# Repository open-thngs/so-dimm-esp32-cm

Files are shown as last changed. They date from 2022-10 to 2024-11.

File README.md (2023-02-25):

# SO-DIMM-ESP32-S2-CM

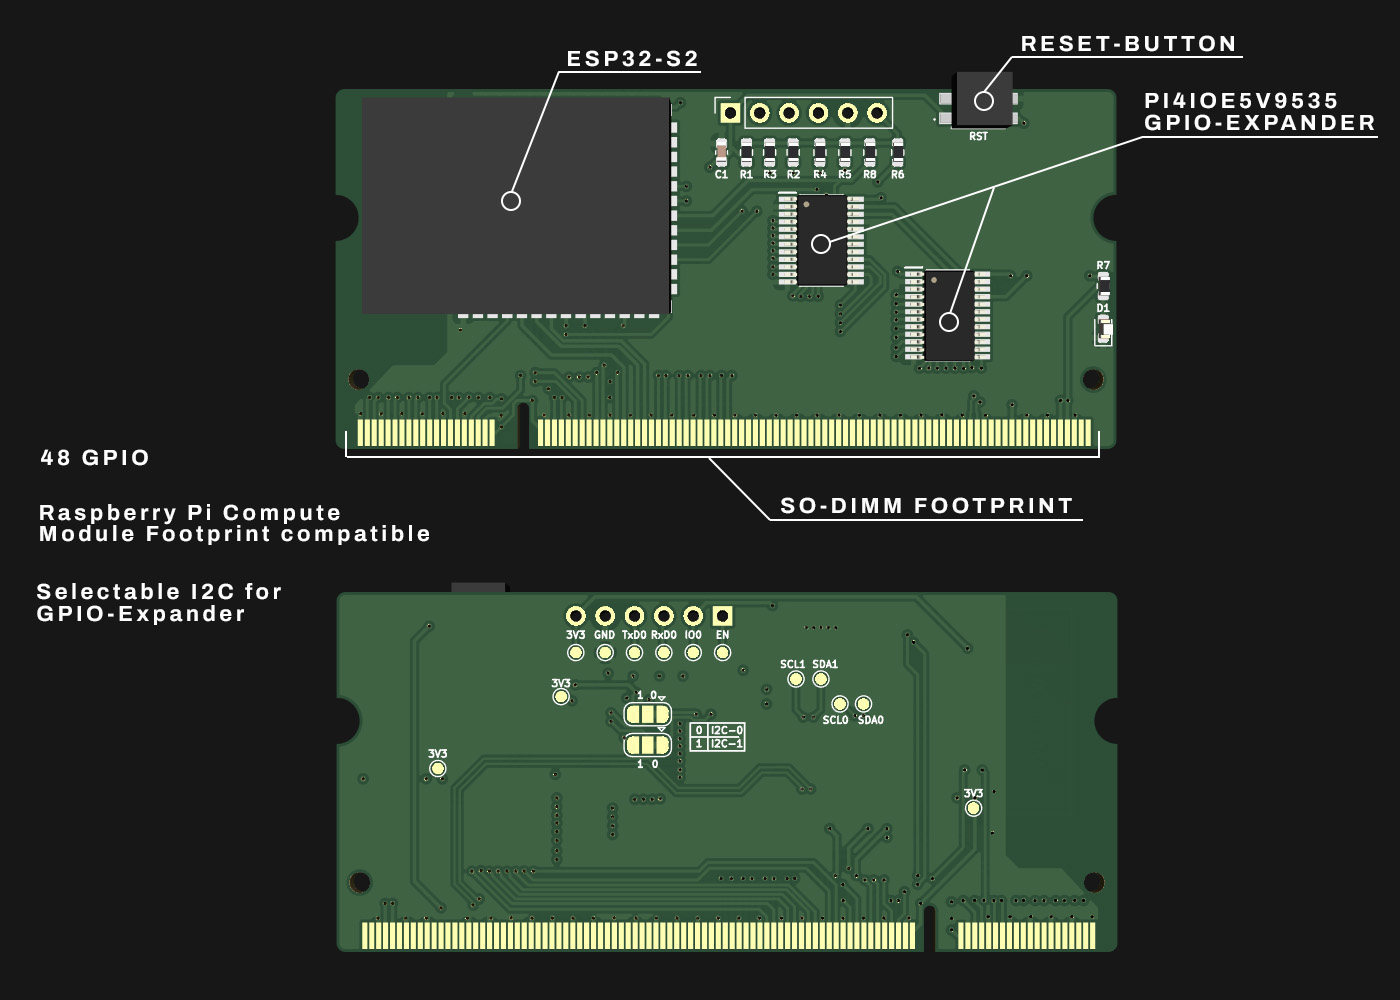
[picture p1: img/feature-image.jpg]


This is a ESP32-S2 based Compute Module to replace the Raspberry Pi's Compute Modules CM2 and CM3. This module is footprint compatible to the Raspberry Pi CM (SO-DIMM-DDR2). The ESP32-S2 brings USB, I2C and SPI.

Because the ESP32 is not running a Linux OS this module can not replace any CM in any project due to its limitations but it might helps others to reduce cost and resources needed to run the project. The ESP32-S2 consumes only 1/3 of the power the CM does. The ESP can also bring WiFi to your project if needed.

The Module also contains 2x GPIO-Expander which are used to be compatible with any GPIO of the Raspberry Pi Compute Module which gives you 48 GPIOs to be used in total.

Features:
- 2x I2C
- 2x SPI
- 1x UART
- USB

## OSHW Certified

[OSHW] DE000133 | Certified open source hardware | oshwa.org/cert

[https://certification.oshwa.org/de000133.html](https://certification.oshwa.org/de000133.html)

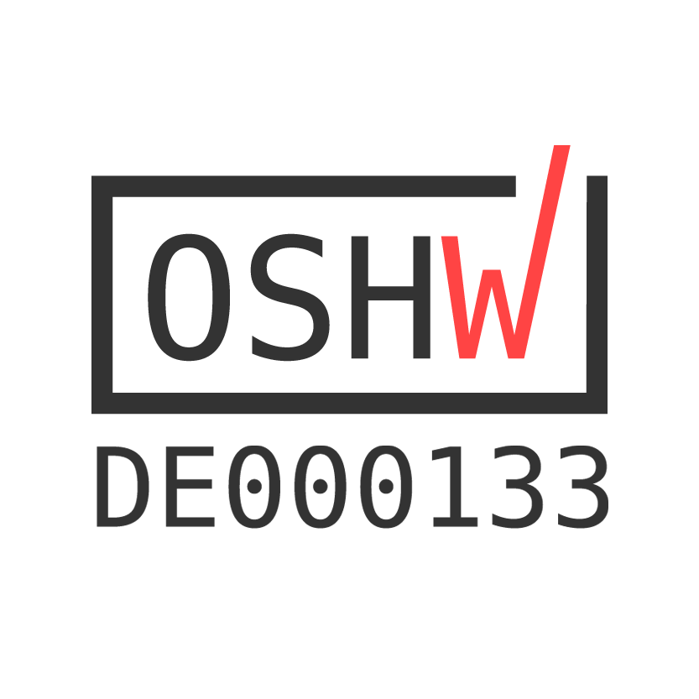
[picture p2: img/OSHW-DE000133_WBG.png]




## GPIO Reference

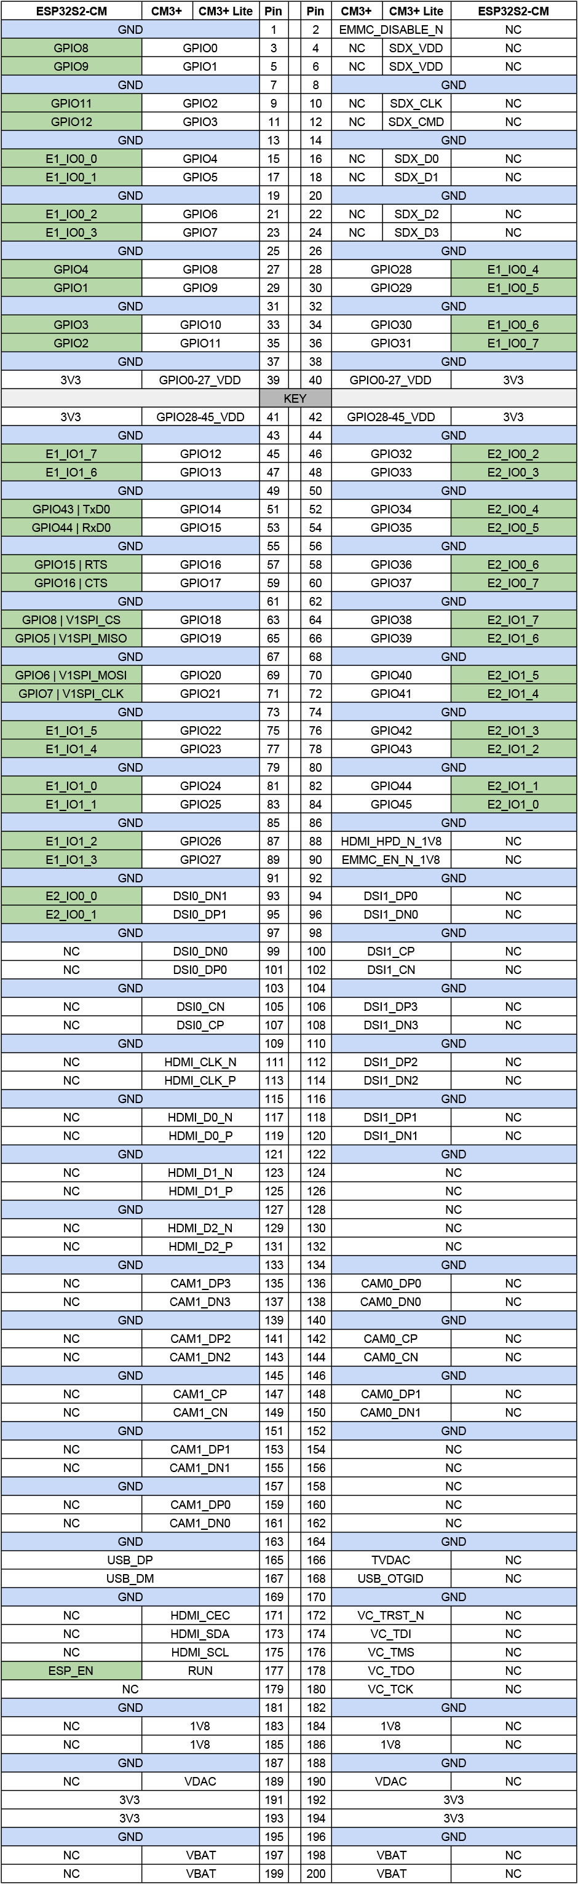
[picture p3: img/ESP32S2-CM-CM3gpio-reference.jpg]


GPIO Expander references E1_IOX_Y = < Expander >_< Bank >_< GPIO >
Example: E1_IO0_2 is the GPIO 2 of the Bank 0 in GPIO Expander 1. GPIO count starts at 0.

GPIO Expander E1 has address 0x20
GPIO Expander E2 has address 0x21

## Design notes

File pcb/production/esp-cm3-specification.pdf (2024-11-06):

### PCB Specifications ESP-CM3

PCB Thickness: | 1.03mm
PCB Layer count: | 4
PCB Surface Finish: | HASL
PCB Color: | Green T/B
PCB Silkscreen: | White T/B
PCB Physical Stackup:
Layer | Type | Thickness
F.Cu | Copper | 0.035mm
Dielectric 1 | PrePreg | 0.255mm
In1.Cu | Copper | 0.035mm
Dielectric 2 | Core | 0.36mm
In2.Cu | Copper | 0.035mm
Dielectric 3 | PrePreg | 0.255mm
B.Cu | Copper | 0.035mm

### Dimensions

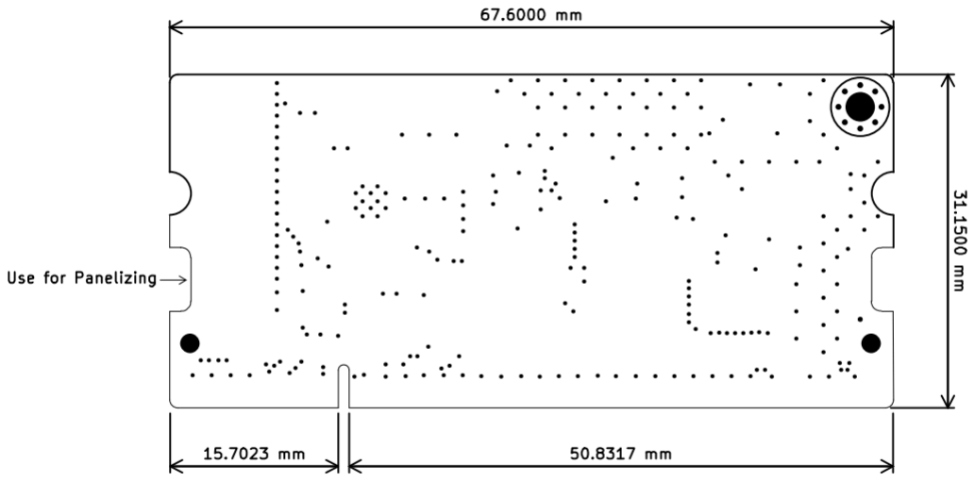
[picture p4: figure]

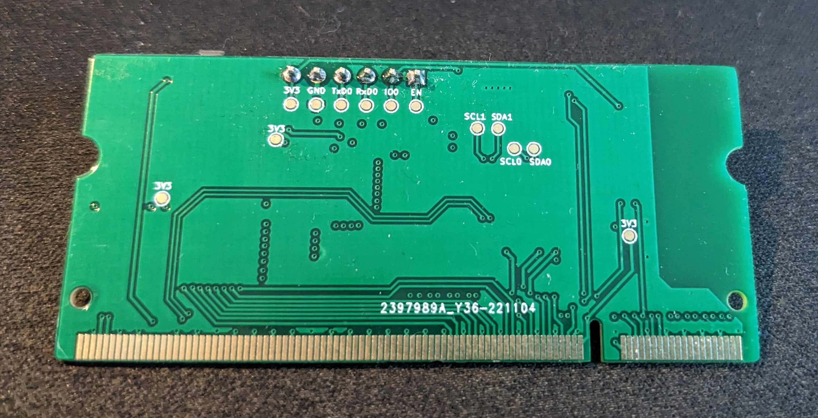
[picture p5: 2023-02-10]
img/img_back.jpg

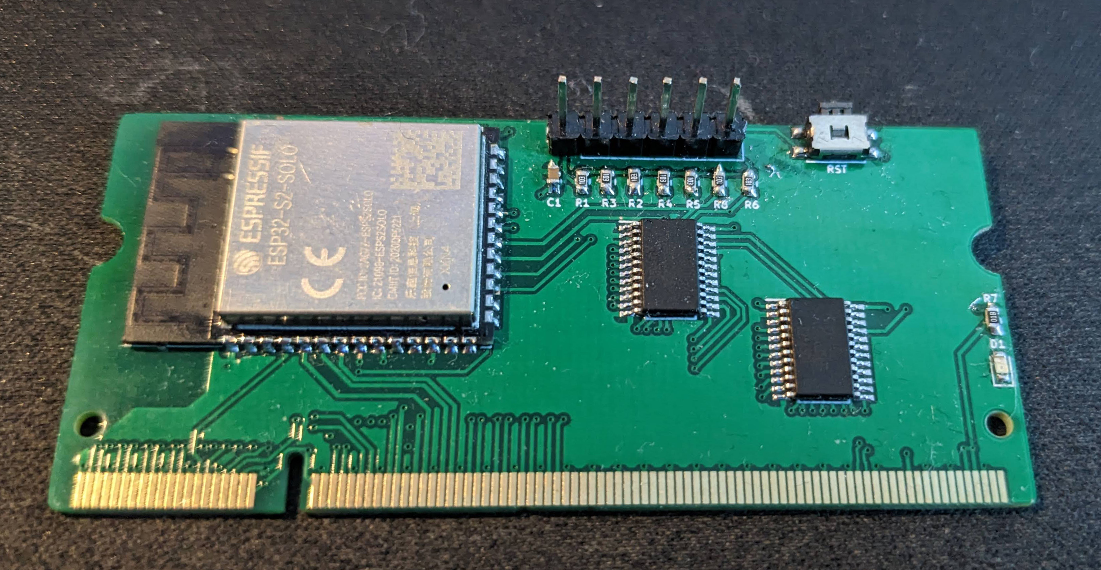
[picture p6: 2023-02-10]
img/img_front.jpg

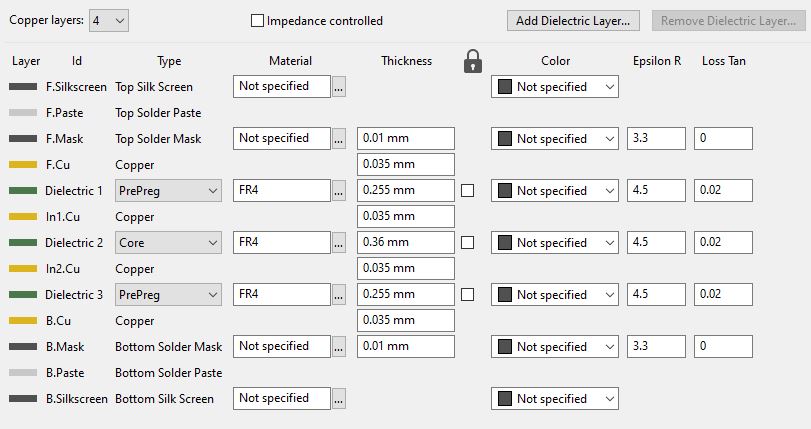
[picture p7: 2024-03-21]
pcb/production/pcb-physical-stackup.JPG

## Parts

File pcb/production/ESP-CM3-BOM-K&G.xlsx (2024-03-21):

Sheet: BIL OF MATERIALS
 |  |  | Kunde: | Mirko Häberlin - open-things
 |  |  | Projektname: | Openthing 1 - ESP-CM3
 |  |  | Menge: | 20, 100
 | KRÜGER & GOTHE GMBH
 | electronic products and services
 | Atzendorfer Str. 19 • 39418 Staßfurt
 | www.kug-ems.de
Pos. | CPN interne Kundenartikelnummer costumer part number | Beschreibung Artikelparameter describtion | Referenzen credentials | T/B | Menge Quantity | MPN Herstellerteilenummer manufacturer part number | Hersteller Manufacturer | MPN Alternative 1 | Hersteller Alternative 1 | MPN Alternative 2 | Hersteller Alternative 2 | Bemerkung
0001 |  | Capacitor 0.1µF 0603 | C2, C3, C6 | T | 3 | 0.1uF
0002 |  | Capacitor 10µF 0603 | C4 | T | 1 | 10uF
0003 |  | Capacitor 1µF 0603 | C5 | T | 1 | 1uF
0004 |  | LED in Rot 0603 | D1 | T | 1 | LED RED
0005 |  | GPIO Expander TSSOP-24 | IC1, IC2 | T | 2 | PI4IOE5V9535LEX | Diodes Incorporated
0006 |  | Widerstand 10k 0603 | R2, R3, R4, R5, R6, R8, R9 | T | 7 | 10k
0007 |  | Widerstand 1k 0603 | R7 | T | 1 | 1k
0008 |  | ESP32-S3 Module | U2 | T | 1 | ESP32-S3-WROOM-1-N8 | Espressif
0009
0010
0011
0012
0013
0014
0015
0016
0017
0018
0019
0020
0021
0022
0023
0024
0025

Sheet: bom
Designator | Footprint | Quantity | Value | LCSC Part #
C2, C3, C6 | 603 | 3 | 0.1uF
C4 | 603 | 1 | 10uF
C5 | 603 | 1 | 1uF
D1 | 603 | 1 | LED_RED
IC1, IC2 | SOP65P640X120-24N | 2 | PI4IOE5V9535LEX
R2, R3, R4, R5, R6, R8, R9 | 603 | 7 | 10k
R7 | 603 | 1 | 1k
U2 | ESP32-S2-SOLO | 1 | ESP32-S3-WROOM-1-N8

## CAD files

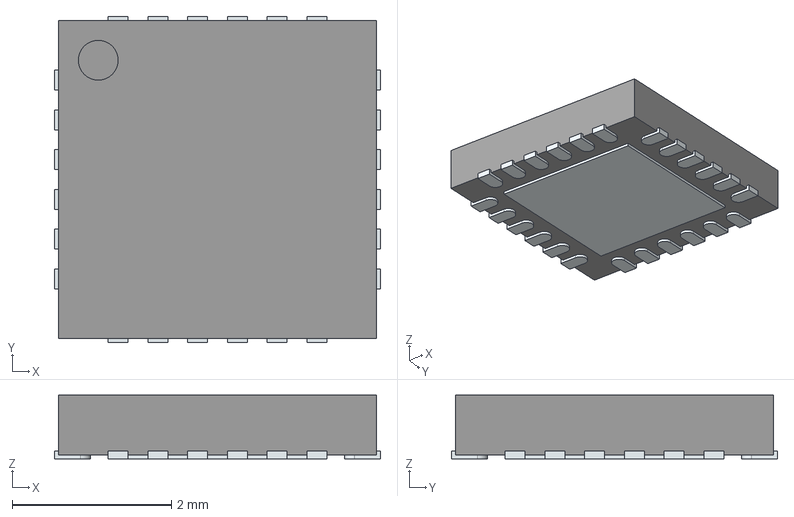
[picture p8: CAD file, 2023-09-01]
pcb/components/AW9523BTQR/3D/AW9523BTQR.stp
4.10 x 4.10 x 0.8 mm
ThermalPin
PinsArrayLR
PinsArrayTB

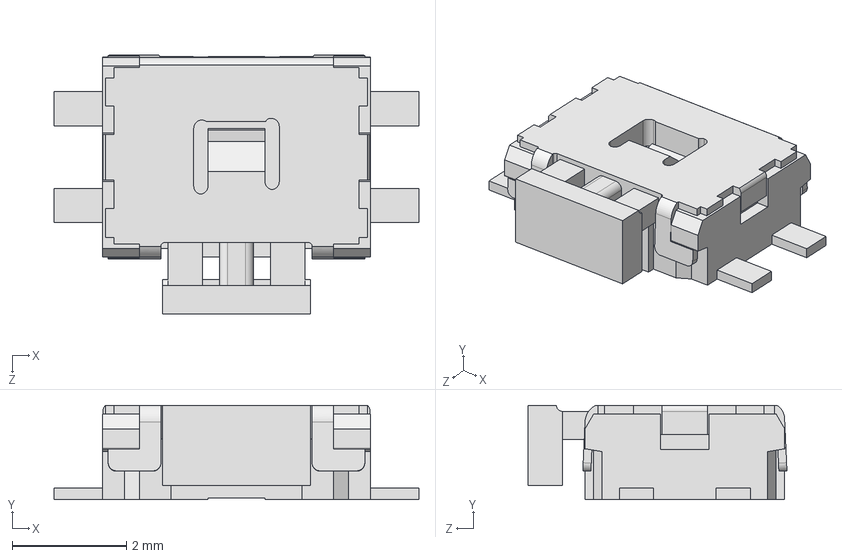
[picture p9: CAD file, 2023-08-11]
pcb/components/EVQ-PUA02K/3D/EVQPU-JA-02K.STEP
6.40 x 1.65 x 4.54 mm

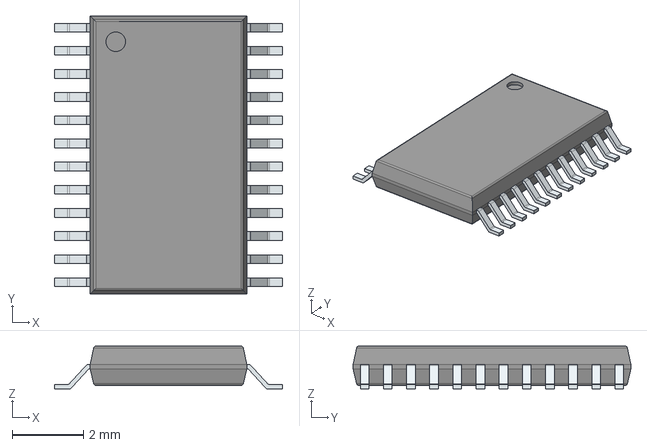
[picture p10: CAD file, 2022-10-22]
pcb/components/PI4IOE5V9535LEX/3D/PI4IOE5V9535LEX.stp
6.40 x 7.80 x 1.20 mm
PinsArrayLR

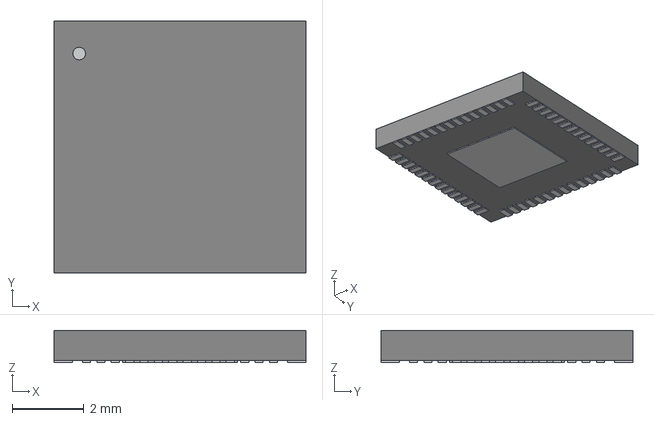
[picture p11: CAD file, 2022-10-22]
pcb/components/RP2040/3D/IC57_RP2040.step
7.01 x 7.01 x 0.892 mm

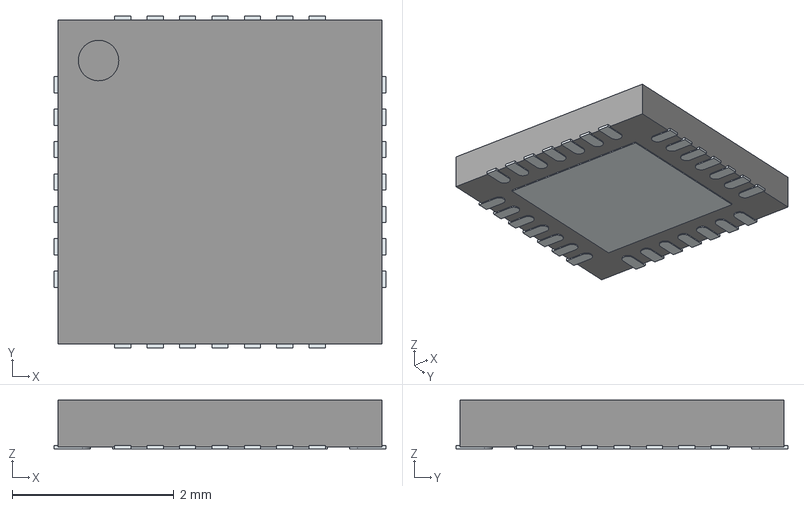
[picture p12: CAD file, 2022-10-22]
pcb/components/SX1503I091TRT/3D/SX1503I091TRT.stp
4.10 x 4.10 x 0.6 mm
ThermalPin
PinsArrayLR
PinsArrayTB

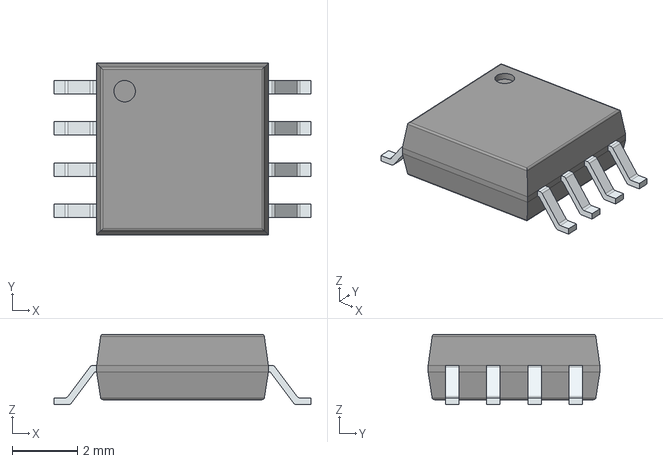
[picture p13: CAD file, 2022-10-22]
pcb/components/W25Q32JVSSIQ_TR/3D/W25Q32JVSSIQ_TR.stp
7.90 x 5.28 x 2.16 mm
PinsArrayLR

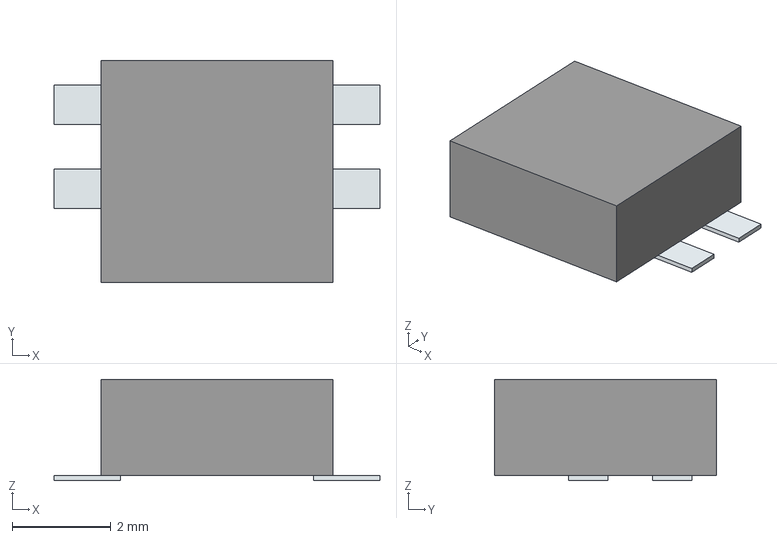
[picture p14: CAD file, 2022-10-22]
pcb/components/EVQ-PUA02K/3D/EVQ-PUA02K.stp
6.60 x 4.50 x 2.05 mm
Pins

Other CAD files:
pcb/components/EVQ-PUA02K/3D/EVQ-PUA02K.stl

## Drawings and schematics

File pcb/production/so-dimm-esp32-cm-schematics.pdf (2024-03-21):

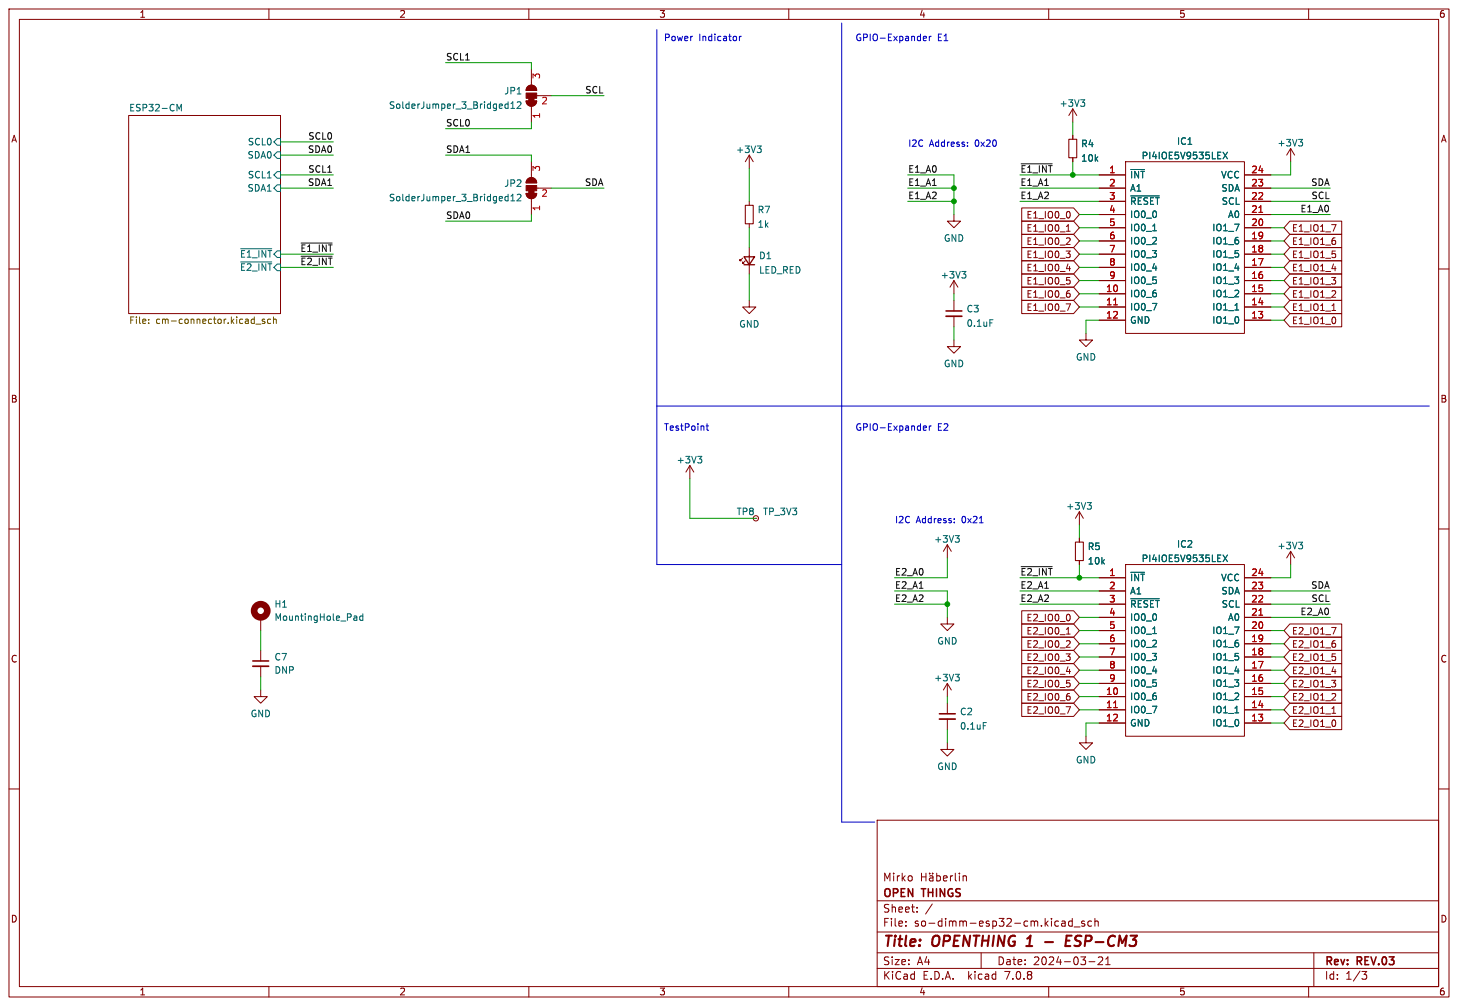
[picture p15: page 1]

Id: 1/3 Title: OPENTHING 1 - ESP-CM3

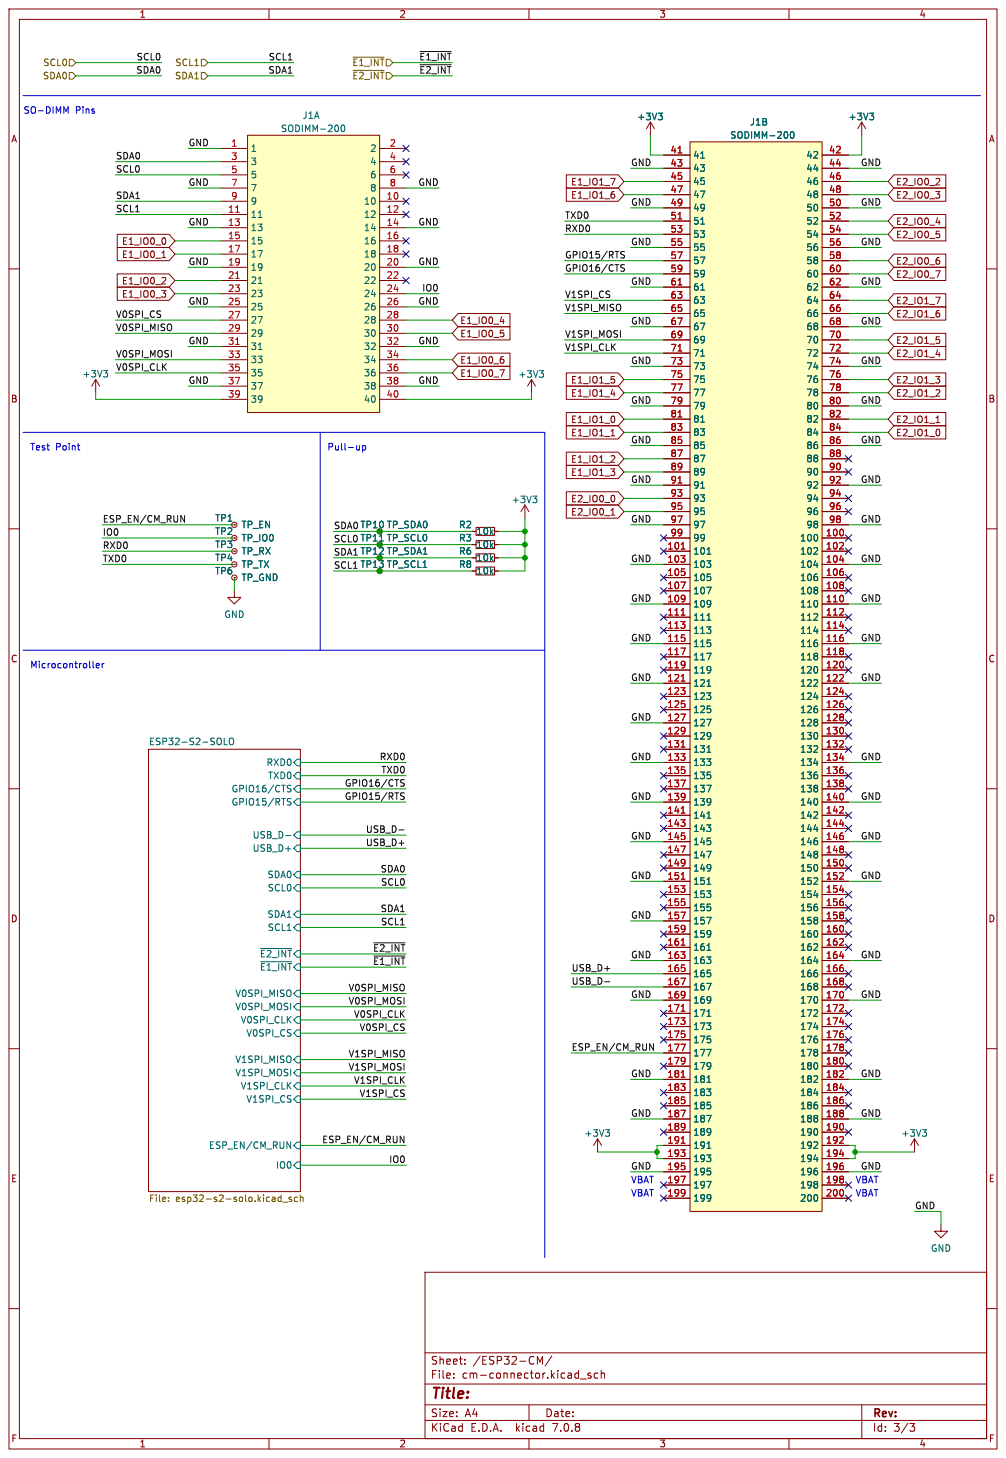
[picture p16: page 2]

Id: 3/3 Title: File: cm-connector.kicad_sch Sheet: /ESP32-CM/

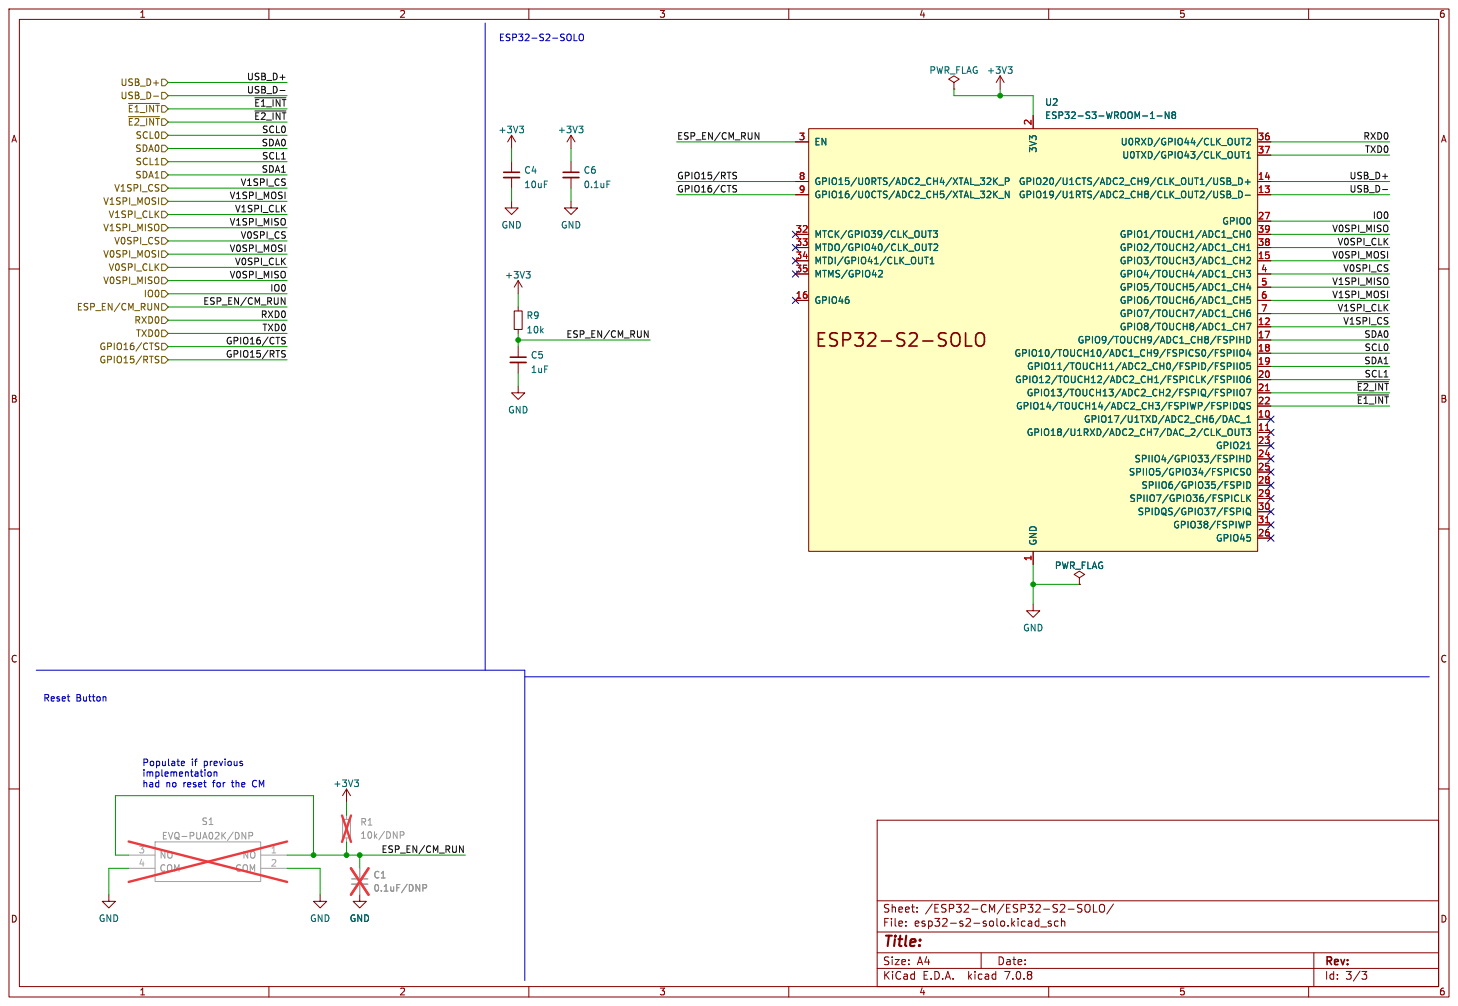
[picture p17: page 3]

2 GPIO12/TOUCH12/ADC2_CH1/FSPICLK/FSPIIO6 20 GPIO13/TOUCH13/ADC2_CH2/FSPIQ/FSPIIO7 21 GPIO14/TOUCH14/ADC2_CH3/FSPIWP/FSPIDQS 22 GPIO21 23 SPIIO4/GPIO33/FSPIHD 24 SPIIO5/GPIO34/FSPICS0 25 GPIO45 26 GPIO0 27 SPIIO6/GPIO35/FSPID 28 SPIIO7/GPIO36/FSPICLK 29 EN 3 SPIDQS/GPIO37/FSPIQ 30 GPIO38/FSPIWP 31 MTCK/GPIO39/CLK_OUT3 32 MTDO/GPIO40/CLK_OUT2 33 MTDI/GPIO41/CLK_OUT1 34 MTMS/GPIO42 35 U0RXD/GPIO44/CLK_OUT2 36 U0TXD/GPIO43/CLK_OUT1 37 GPIO2/TOUCH2/ADC1_CH1 38 GPIO1/TOUCH1/ADC1_CH0 39 GPIO4/TOUCH4/ADC1_CH3 4 GPIO5/TOUCH5/ADC1_CH4 5 GPIO6/TOUCH6/ADC1_CH5 6 GPIO7/TOUCH7/ADC1_CH6 7 GPIO15/U0RTS/ADC2_CH4/XTAL_32K_P 8 GPIO16/U0CTS/ADC2_CH5/XTAL_32K_N 9 U2ESP32-S3-WROOM-1-N8

2 GPIO12/TOUCH12/ADC2_CH1/FSPICLK/FSPIIO6 20 GPIO13/TOUCH13/ADC2_CH2/FSPIQ/FSPIIO7 21 GPIO14/TOUCH14/ADC2_CH3/FSPIWP/FSPIDQS 22 GPIO21 23 SPIIO4/GPIO33/FSPIHD 24 SPIIO5/GPIO34/FSPICS0 25 GPIO45 26 GPIO0 27 SPIIO6/GPIO35/FSPID 28 SPIIO7/GPIO36/FSPICLK 29 EN 3 SPIDQS/GPIO37/FSPIQ 30 GPIO38/FSPIWP 31 MTCK/GPIO39/CLK_OUT3 32 MTDO/GPIO40/CLK_OUT2 33 MTDI/GPIO41/CLK_OUT1 34 MTMS/GPIO42 35 U0RXD/GPIO44/CLK_OUT2 36 U0TXD/GPIO43/CLK_OUT1 37 GPIO2/TOUCH2/ADC1_CH1 38 GPIO1/TOUCH1/ADC1_CH0 39 GPIO4/TOUCH4/ADC1_CH3 4 GPIO5/TOUCH5/ADC1_CH4 5 GPIO6/TOUCH6/ADC1_CH5 6 GPIO7/TOUCH7/ADC1_CH6 7 GPIO15/U0RTS/ADC2_CH4/XTAL_32K_P 8 GPIO16/U0CTS/ADC2_CH5/XTAL_32K_N 9 C1

implementation
had no reset for the CM

Id: 3/3 Title: File: esp32-s2-solo.kicad_sch Sheet: /ESP32-CM/ESP32-S2-SOLO/

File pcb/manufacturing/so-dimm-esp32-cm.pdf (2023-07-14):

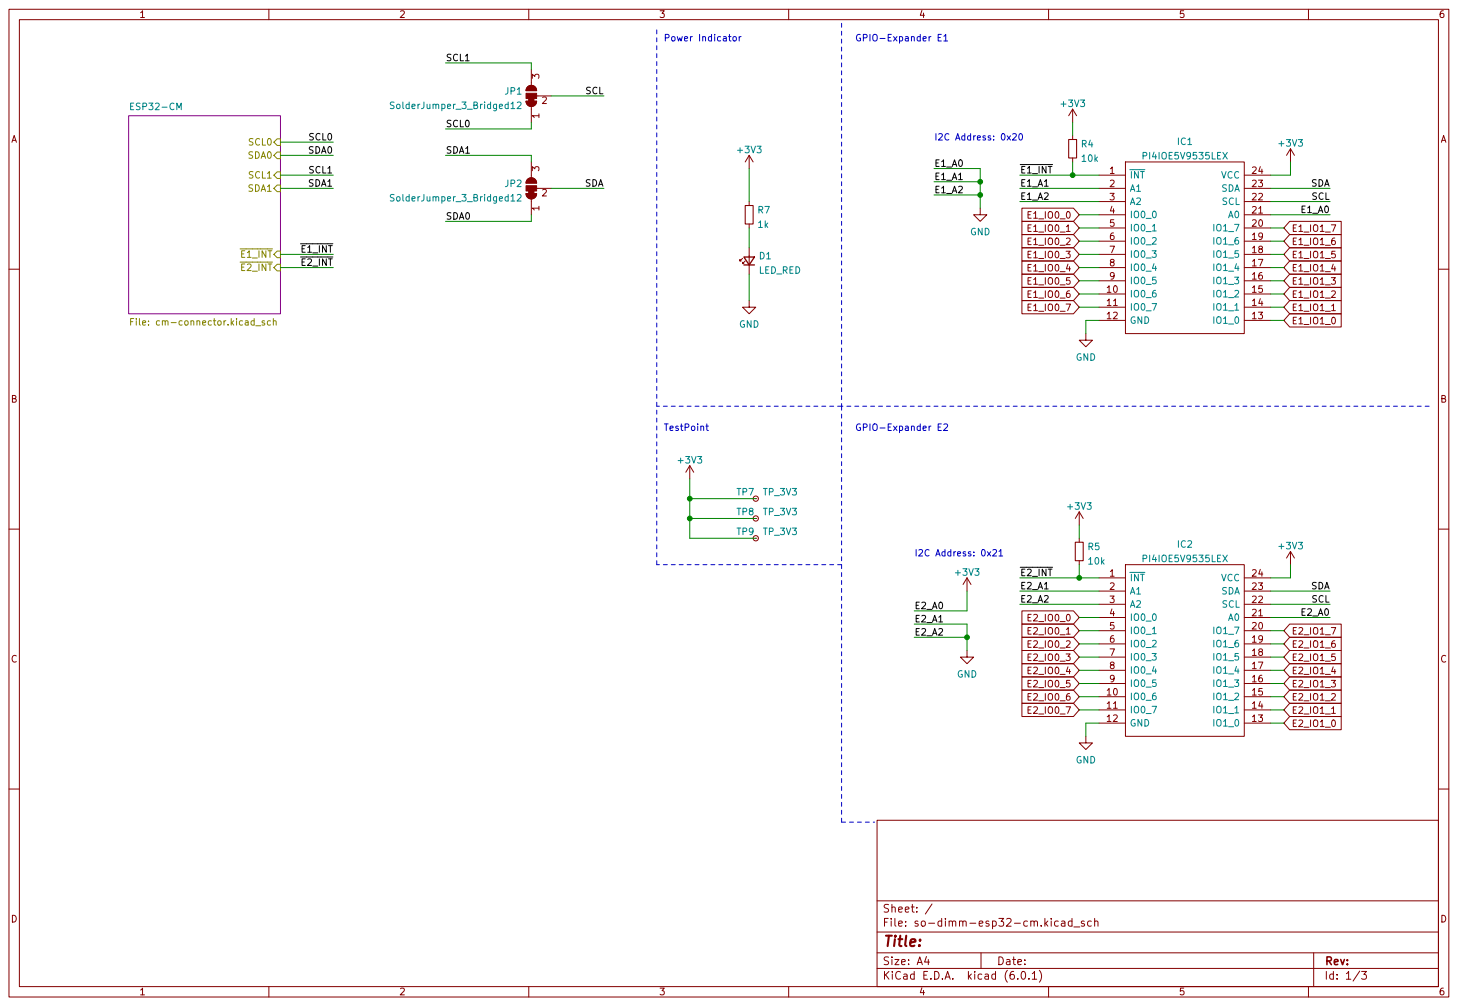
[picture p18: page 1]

File: so-dimm-esp32-cm.kicad_sch Sheet: /
Id: 1/3 Title:

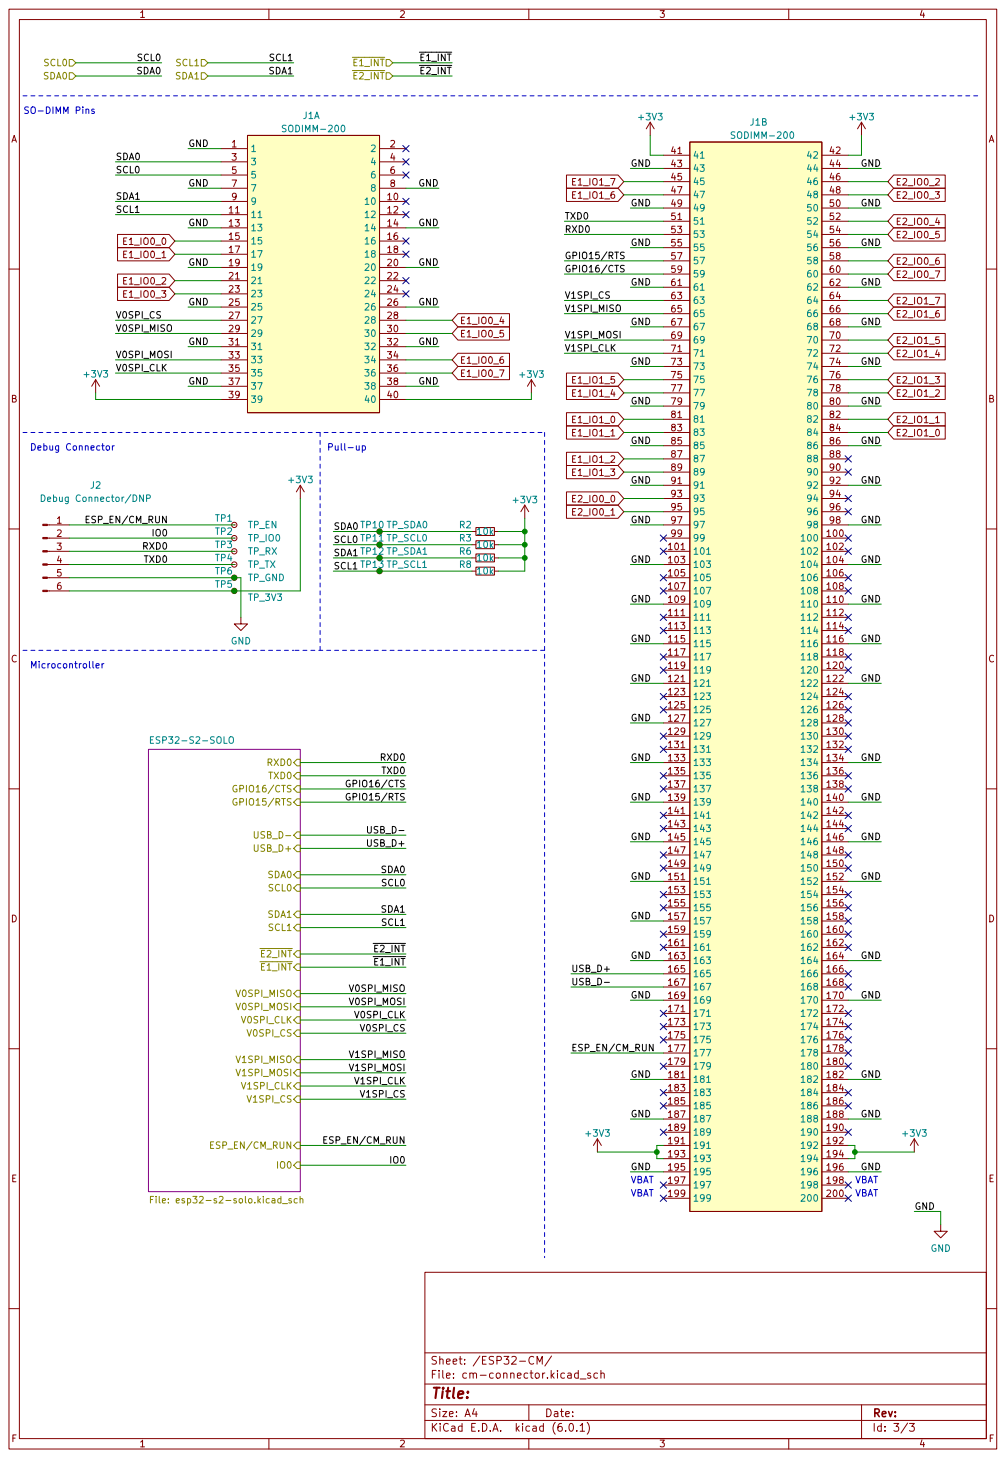
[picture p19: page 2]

Pull-up SO-DIMM Pins

File: cm-connector.kicad_sch Sheet: /ESP32-CM/

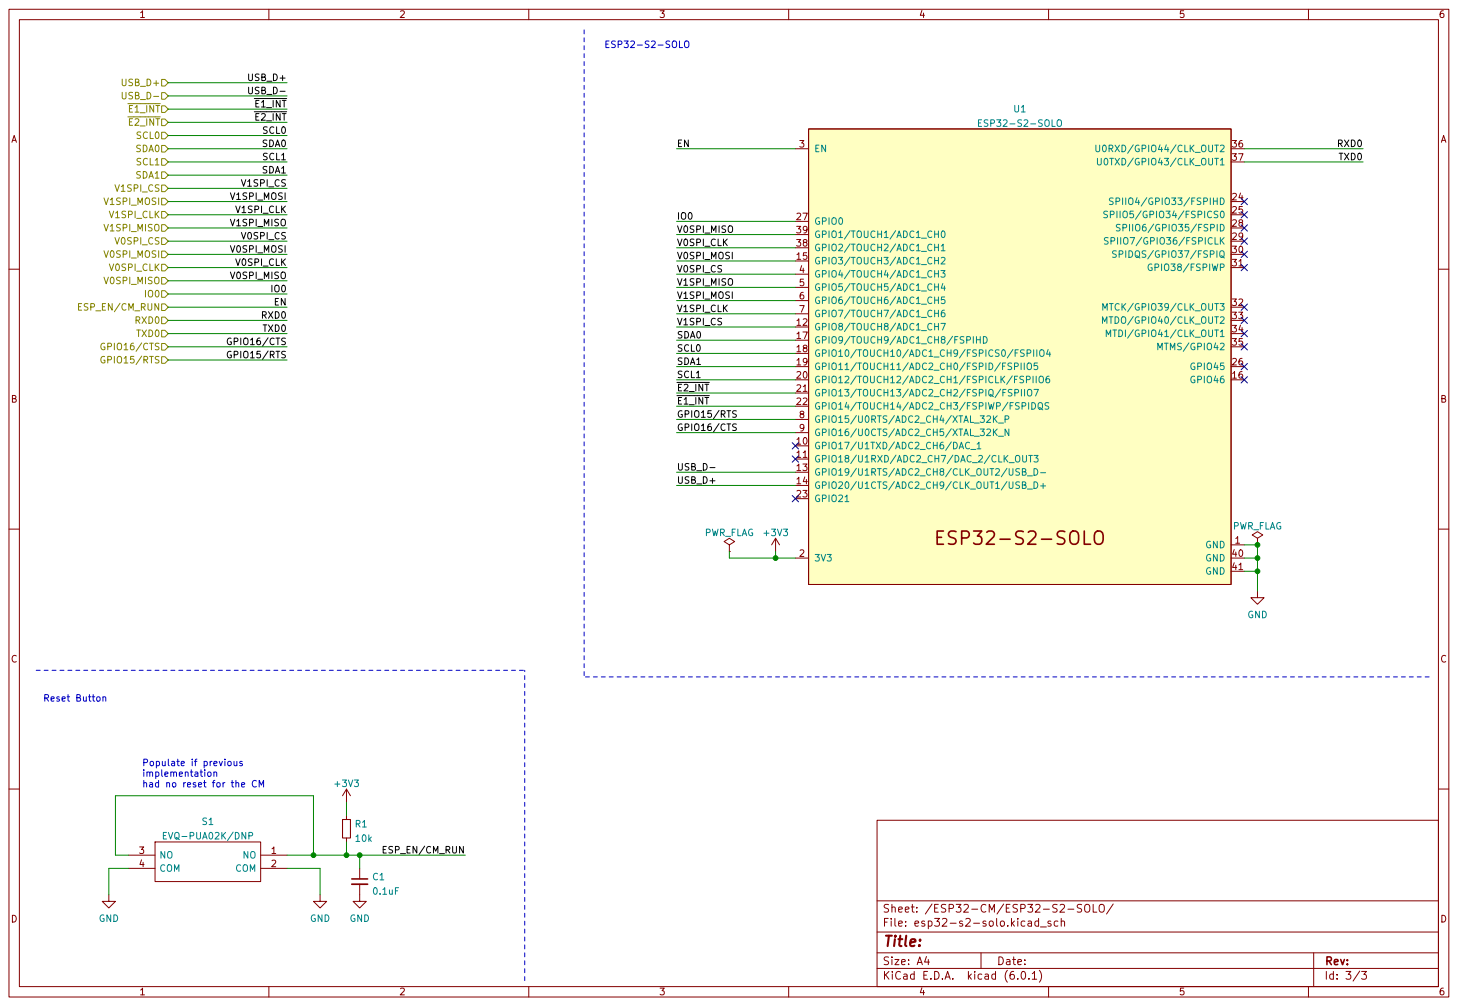
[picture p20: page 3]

Populate if previous
implementation had no reset for the CM

File: esp32-s2-solo.kicad_sch Sheet: /ESP32-CM/ESP32-S2-SOLO/ +3V3 GND

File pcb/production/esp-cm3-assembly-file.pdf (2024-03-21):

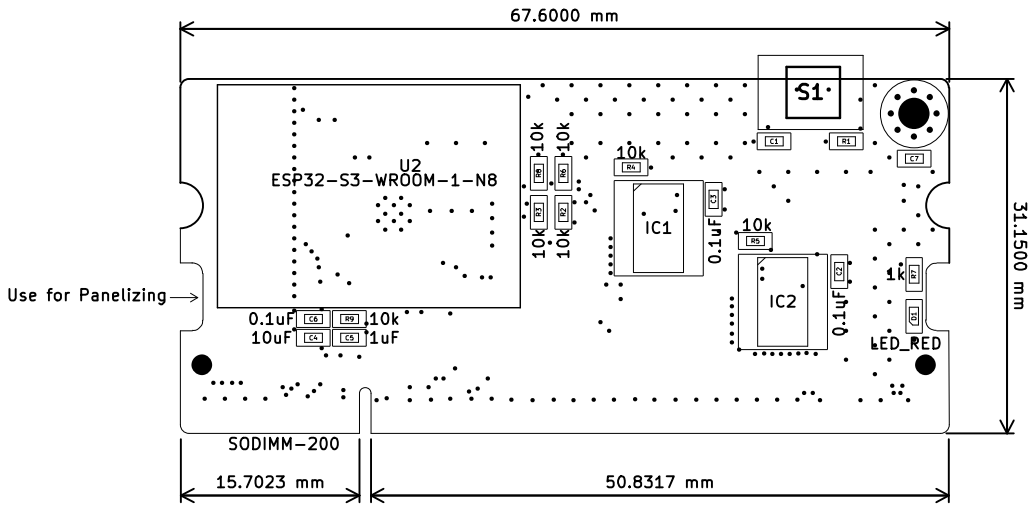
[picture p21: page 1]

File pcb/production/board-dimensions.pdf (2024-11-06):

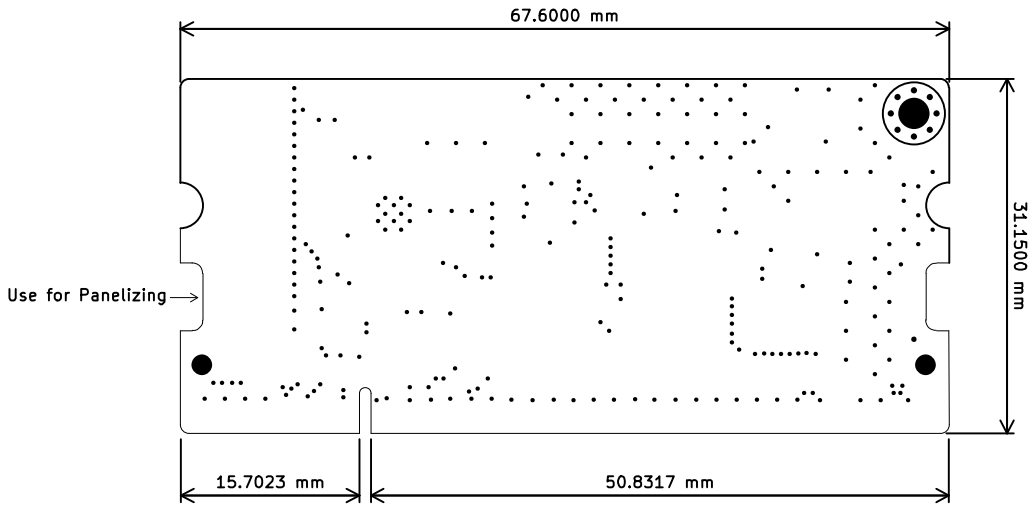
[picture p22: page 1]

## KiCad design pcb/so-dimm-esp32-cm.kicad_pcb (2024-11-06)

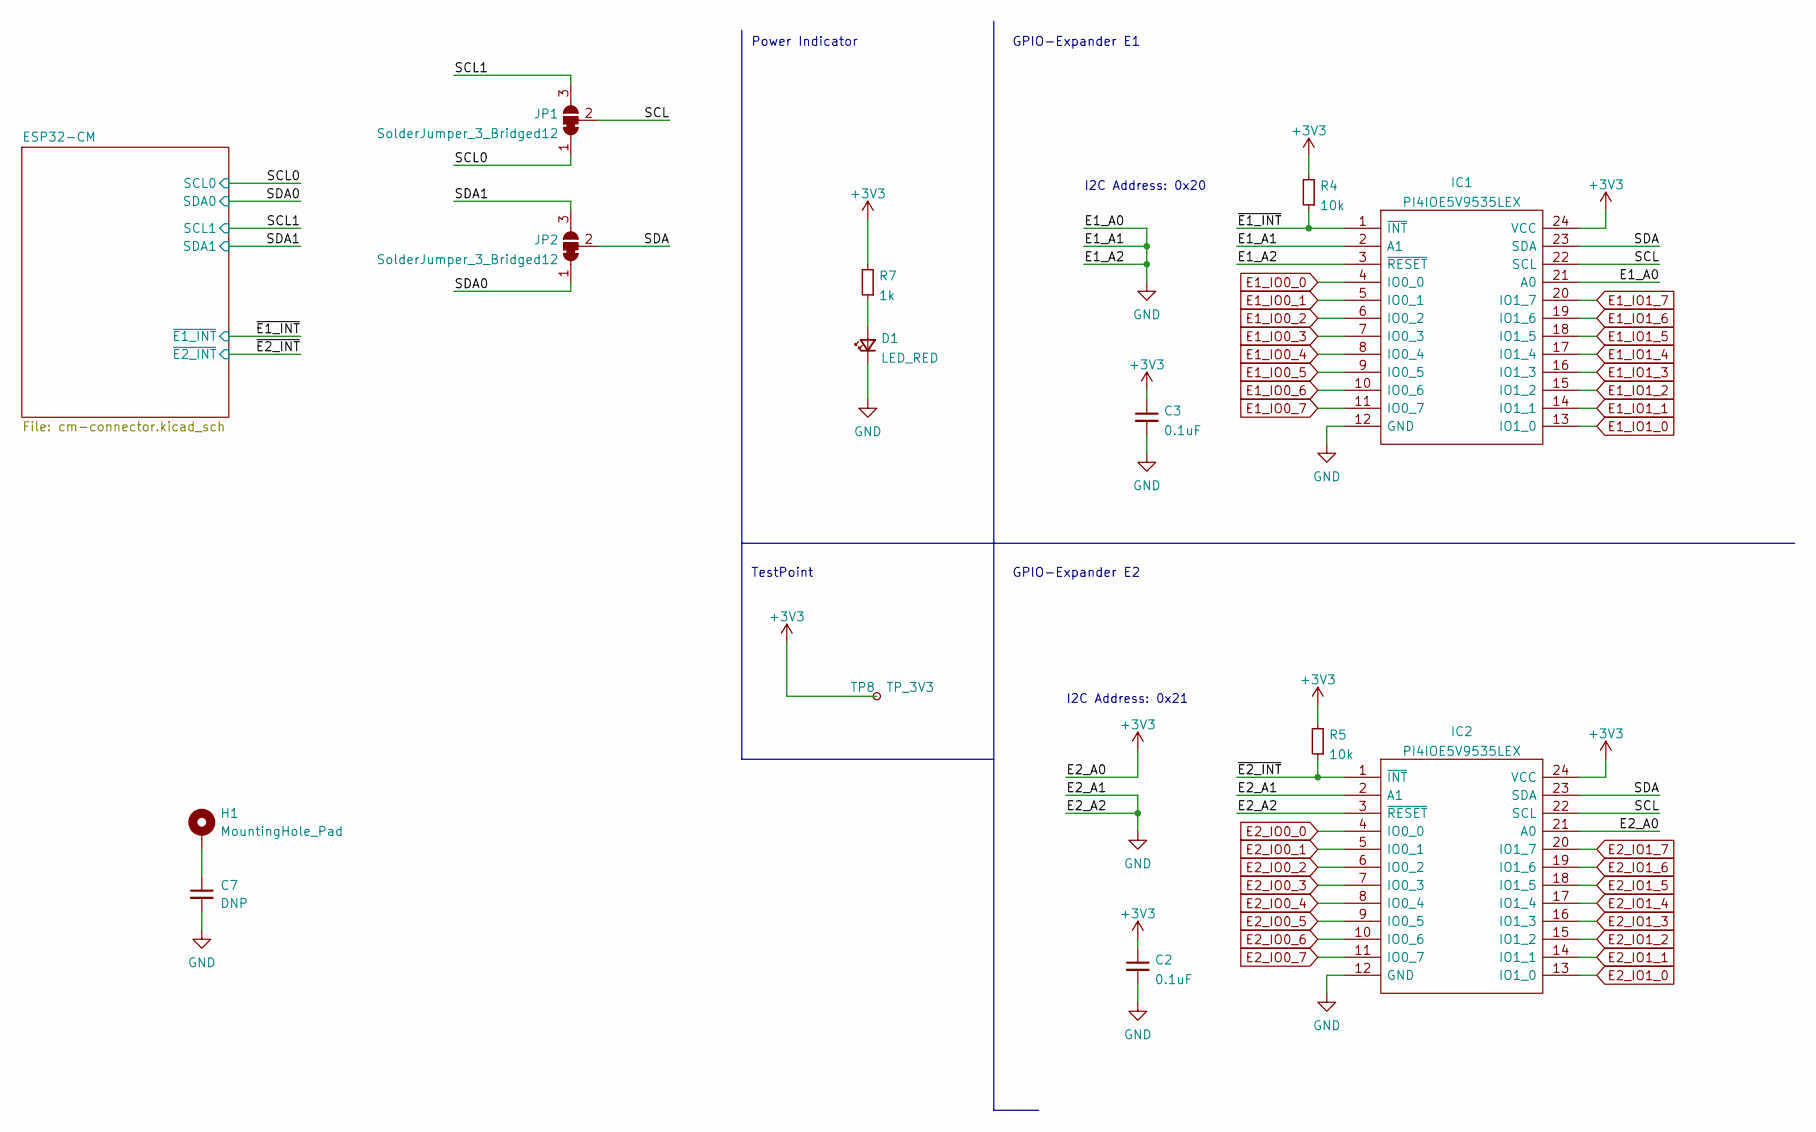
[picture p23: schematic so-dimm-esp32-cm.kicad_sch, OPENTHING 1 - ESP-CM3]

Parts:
C2, C3: 0.1uF; C_0603_1608Metric
C7: DNP; C_0603_1608Metric
D1: LED_RED; LED_0603_1608Metric
H1: MountingHole_Pad; MountingHole_2.7mm_Pad_Via
IC1, IC2: PI4IOE5V9535LEX; SOP65P640X120-24N; Manufacturer_Part_Number PI4IOE5V9535LEX; Mouser Part Number 729-PI4IOE5V9535LEX
JP1, JP2: SolderJumper_3_Bridged12; SolderJumper-3_P1.3mm_Bridged12_RoundedPad1.0x1.5mm
R4, R5: 10k; R_0603_1608Metric
R7: 1k; R_0603_1608Metric
TP8: TP_3V3; TestPoint_Pad_D1.0mm

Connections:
+3V3: C2.1, C3.1, IC1.24 (VCC), IC2.21 (A0), IC2.24 (VCC), R4.2, R5.2, R7.2, TP8.1; also elsewhere on the board
/SCL: IC1.22 (SCL), IC2.22 (SCL), JP1.2 (C)
/SCL0: JP1.1 (A); also elsewhere on the board
/SCL1: JP1.3 (B); also elsewhere on the board
/SDA: IC1.23 (SDA), IC2.23 (SDA), JP2.2 (C)
/SDA0: JP2.1 (A); also elsewhere on the board
/SDA1: JP2.3 (B); also elsewhere on the board
/~E1_INT: IC1.1 (~INT), R4.1; also elsewhere on the board
/~E2_INT: IC2.1 (~INT), R5.1; also elsewhere on the board
E1_IO0_0: IC1.4 (IO0_0); also elsewhere on the board
E1_IO0_1: IC1.5 (IO0_1); also elsewhere on the board
E1_IO0_2: IC1.6 (IO0_2); also elsewhere on the board
E1_IO0_3: IC1.7 (IO0_3); also elsewhere on the board
E1_IO0_4: IC1.8 (IO0_4); also elsewhere on the board
E1_IO0_5: IC1.9 (IO0_5); also elsewhere on the board
E1_IO0_6: IC1.10 (IO0_6); also elsewhere on the board
E1_IO0_7: IC1.11 (IO0_7); also elsewhere on the board
E1_IO1_0: IC1.13 (IO1_0); also elsewhere on the board
E1_IO1_1: IC1.14 (IO1_1); also elsewhere on the board
E1_IO1_2: IC1.15 (IO1_2); also elsewhere on the board
E1_IO1_3: IC1.16 (IO1_3); also elsewhere on the board
E1_IO1_4: IC1.17 (IO1_4); also elsewhere on the board
E1_IO1_5: IC1.18 (IO1_5); also elsewhere on the board
E1_IO1_6: IC1.19 (IO1_6); also elsewhere on the board
E1_IO1_7: IC1.20 (IO1_7); also elsewhere on the board
E2_IO0_0: IC2.4 (IO0_0); also elsewhere on the board
E2_IO0_1: IC2.5 (IO0_1); also elsewhere on the board
E2_IO0_2: IC2.6 (IO0_2); also elsewhere on the board
E2_IO0_3: IC2.7 (IO0_3); also elsewhere on the board
E2_IO0_4: IC2.8 (IO0_4); also elsewhere on the board
E2_IO0_5: IC2.9 (IO0_5); also elsewhere on the board
E2_IO0_6: IC2.10 (IO0_6); also elsewhere on the board
E2_IO0_7: IC2.11 (IO0_7); also elsewhere on the board
E2_IO1_0: IC2.13 (IO1_0); also elsewhere on the board
E2_IO1_1: IC2.14 (IO1_1); also elsewhere on the board
E2_IO1_2: IC2.15 (IO1_2); also elsewhere on the board
E2_IO1_3: IC2.16 (IO1_3); also elsewhere on the board
E2_IO1_4: IC2.17 (IO1_4); also elsewhere on the board
E2_IO1_5: IC2.18 (IO1_5); also elsewhere on the board
E2_IO1_6: IC2.19 (IO1_6); also elsewhere on the board
E2_IO1_7: IC2.20 (IO1_7); also elsewhere on the board
GND: C2.2, C3.2, C7.2, D1.1 (K), IC1.2 (A1), IC1.3 (~RESET), IC1.12 (GND), IC1.21 (A0), IC2.2 (A1), IC2.3 (~RESET), IC2.12 (GND); also elsewhere on the board
unnamed: C7.1, H1.1
unnamed: D1.2 (A), R7.1

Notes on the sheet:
I2C Address: 0x20
GPIO-Expander E1
TestPoint
I2C Address: 0x21
Power Indicator
GPIO-Expander E2

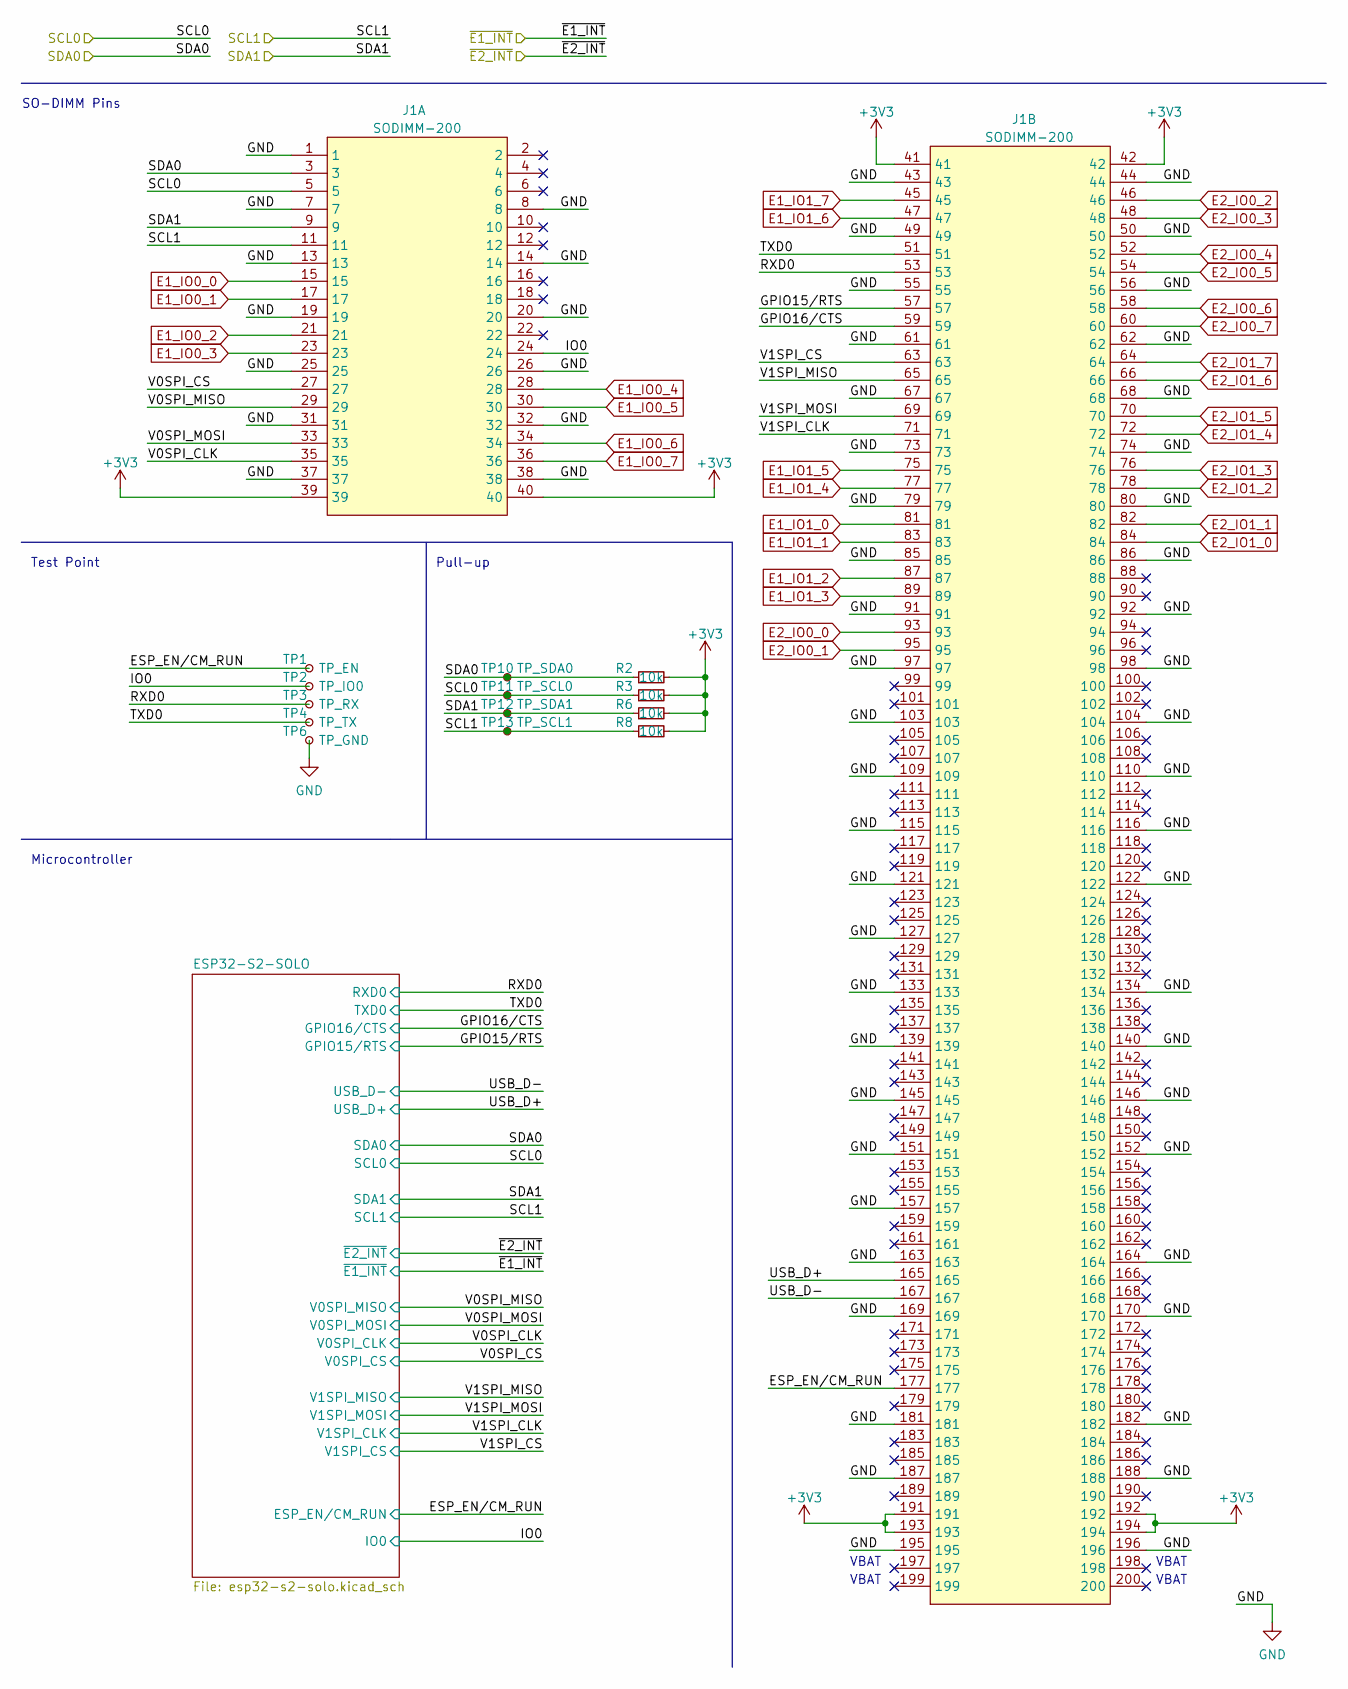
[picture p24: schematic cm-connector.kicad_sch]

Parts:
J1: SODIMM-200; SODIMM_DDR2_EDGE
R2, R3, R6, R8: 10k; R_0603_1608Metric
TP1: TP_EN; TestPoint_Pad_D1.0mm
TP2: TP_IO0; TestPoint_Pad_D1.0mm
TP3: TP_RX; TestPoint_Pad_D1.0mm
TP4: TP_TX; TestPoint_Pad_D1.0mm
TP6: TP_GND; TestPoint_Pad_D1.0mm
TP10: TP_SDA0; TestPoint_Pad_D1.0mm
TP11: TP_SCL0; TestPoint_Pad_D1.0mm
TP12: TP_SDA1; TestPoint_Pad_D1.0mm
TP13: TP_SCL1; TestPoint_Pad_D1.0mm

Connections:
+3V3: J1.39, J1.40, J1.41, J1.42, J1.191, J1.192, J1.193, J1.194, R2.2, R3.2, R6.2, R8.2; also elsewhere on the board
/ESP32-CM/ESP_EN/CM_RUN: J1.177, TP1.1; also elsewhere on the board
/ESP32-CM/GPIO15/RTS: J1.57; also elsewhere on the board
/ESP32-CM/GPIO16/CTS: J1.59; also elsewhere on the board
/ESP32-CM/IO0: J1.24, TP2.1; also elsewhere on the board
/ESP32-CM/RXD0: J1.53, TP3.1; also elsewhere on the board
/ESP32-CM/TXD0: J1.51, TP4.1; also elsewhere on the board
/ESP32-CM/USB_D+: J1.165; also elsewhere on the board
/ESP32-CM/USB_D-: J1.167; also elsewhere on the board
/ESP32-CM/V0SPI_CLK: J1.35; also elsewhere on the board
/ESP32-CM/V0SPI_CS: J1.27; also elsewhere on the board
/ESP32-CM/V0SPI_MISO: J1.29; also elsewhere on the board
/ESP32-CM/V0SPI_MOSI: J1.33; also elsewhere on the board
/ESP32-CM/V1SPI_CLK: J1.71; also elsewhere on the board
/ESP32-CM/V1SPI_CS: J1.63; also elsewhere on the board
/ESP32-CM/V1SPI_MISO: J1.65; also elsewhere on the board
/ESP32-CM/V1SPI_MOSI: J1.69; also elsewhere on the board
/SCL0: J1.5, R3.1, TP11.1; also elsewhere on the board
/SCL1: J1.11, R8.1, TP13.1; also elsewhere on the board
/SDA0: J1.3, R2.1, TP10.1; also elsewhere on the board
/SDA1: J1.9, R6.1, TP12.1; also elsewhere on the board
E1_IO0_0: J1.15; also elsewhere on the board
E1_IO0_1: J1.17; also elsewhere on the board
E1_IO0_2: J1.21; also elsewhere on the board
E1_IO0_3: J1.23; also elsewhere on the board
E1_IO0_4: J1.28; also elsewhere on the board
E1_IO0_5: J1.30; also elsewhere on the board
E1_IO0_6: J1.34; also elsewhere on the board
E1_IO0_7: J1.36; also elsewhere on the board
E1_IO1_0: J1.81; also elsewhere on the board
E1_IO1_1: J1.83; also elsewhere on the board
E1_IO1_2: J1.87; also elsewhere on the board
E1_IO1_3: J1.89; also elsewhere on the board
E1_IO1_4: J1.77; also elsewhere on the board
E1_IO1_5: J1.75; also elsewhere on the board
E1_IO1_6: J1.47; also elsewhere on the board
E1_IO1_7: J1.45; also elsewhere on the board
E2_IO0_0: J1.93; also elsewhere on the board
E2_IO0_1: J1.95; also elsewhere on the board
E2_IO0_2: J1.46; also elsewhere on the board
E2_IO0_3: J1.48; also elsewhere on the board
E2_IO0_4: J1.52; also elsewhere on the board
E2_IO0_5: J1.54; also elsewhere on the board
E2_IO0_6: J1.58; also elsewhere on the board
E2_IO0_7: J1.60; also elsewhere on the board
E2_IO1_0: J1.84; also elsewhere on the board
E2_IO1_1: J1.82; also elsewhere on the board
E2_IO1_2: J1.78; also elsewhere on the board
E2_IO1_3: J1.76; also elsewhere on the board
E2_IO1_4: J1.72; also elsewhere on the board
E2_IO1_5: J1.70; also elsewhere on the board
E2_IO1_6: J1.66; also elsewhere on the board
E2_IO1_7: J1.64; also elsewhere on the board
GND: J1.1, J1.7, J1.8, J1.13, J1.14, J1.19, J1.20, J1.25, J1.26, J1.31, J1.32, J1.37, J1.38, J1.43, J1.44, J1.49, J1.50, J1.55, J1.56, J1.61, J1.62, J1.67, J1.68, J1.73, J1.74, J1.79, J1.80, J1.85, J1.86, J1.91, J1.92, J1.97, J1.98, J1.103, J1.104, J1.109, J1.110, J1.115, J1.116, J1.121, J1.122, J1.127, J1.133, J1.134, J1.139, J1.140, J1.145, J1.146, J1.151, J1.152, J1.157, J1.163, J1.164, J1.169, J1.170, J1.181, J1.182, J1.187, J1.188, J1.195, J1.196, TP6.1; also elsewhere on the board

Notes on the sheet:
Microcontroller
SO-DIMM Pins
VBAT
Pull-up
Test Point

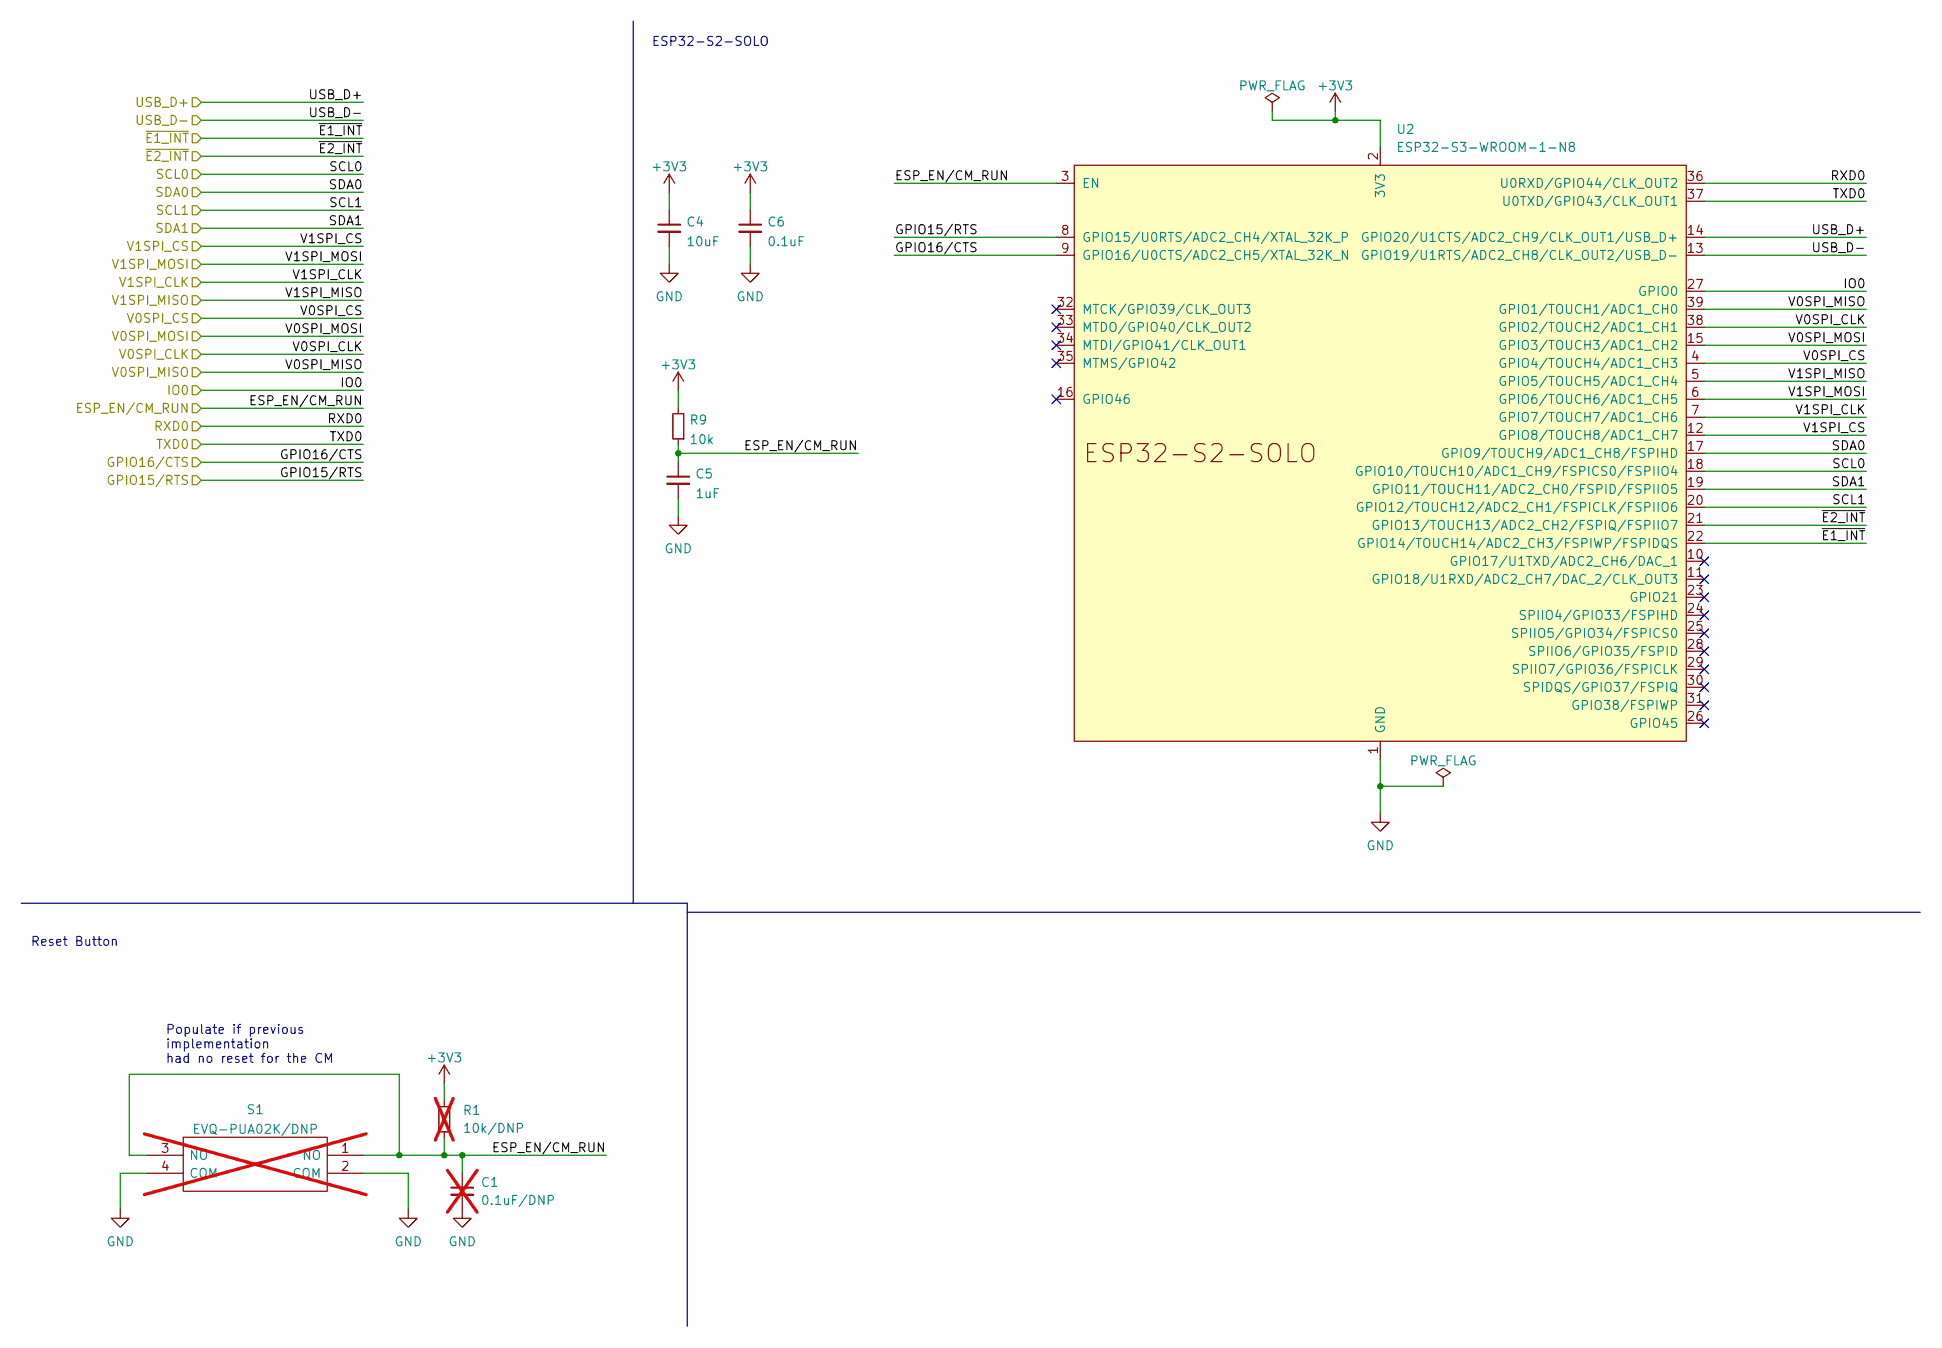
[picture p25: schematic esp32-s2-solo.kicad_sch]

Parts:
C1: 0.1uF/DNP; C_0603_1608Metric; not fitted
C4: 10uF; C_0603_1608Metric
C5: 1uF; C_0603_1608Metric
C6: 0.1uF; C_0603_1608Metric
R1: 10k/DNP; R_0603_1608Metric; not fitted
R9: 10k; R_0603_1608Metric
S1: EVQ-PUA02K/DNP; EVQPUA02K; Manufacturer_Part_Number EVQ-PUA02K; Mouser Part Number 667-EVQ-PUA02K; not fitted
U2: ESP32-S3-WROOM-1-N8; ESP32-S2-SOLO

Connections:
+3V3: C4.1, C6.1, R1.2, R9.2, U2.2 (3V3); also elsewhere on the board
/ESP32-CM/ESP_EN/CM_RUN: C1.1, C5.1, R1.1, R9.1, S1.1 (NO), S1.3 (NO), U2.3 (EN); also elsewhere on the board
/ESP32-CM/GPIO15/RTS: U2.8 (GPIO15/U0RTS/ADC2_CH4/XTAL_32K_P); also elsewhere on the board
/ESP32-CM/GPIO16/CTS: U2.9 (GPIO16/U0CTS/ADC2_CH5/XTAL_32K_N); also elsewhere on the board
/ESP32-CM/IO0: U2.27 (GPIO0); also elsewhere on the board
/ESP32-CM/RXD0: U2.36 (U0RXD/GPIO44/CLK_OUT2); also elsewhere on the board
/ESP32-CM/TXD0: U2.37 (U0TXD/GPIO43/CLK_OUT1); also elsewhere on the board
/ESP32-CM/USB_D+: U2.14 (GPIO20/U1CTS/ADC2_CH9/CLK_OUT1/USB_D+); also elsewhere on the board
/ESP32-CM/USB_D-: U2.13 (GPIO19/U1RTS/ADC2_CH8/CLK_OUT2/USB_D-); also elsewhere on the board
/ESP32-CM/V0SPI_CLK: U2.38 (GPIO2/TOUCH2/ADC1_CH1); also elsewhere on the board
/ESP32-CM/V0SPI_CS: U2.4 (GPIO4/TOUCH4/ADC1_CH3); also elsewhere on the board
/ESP32-CM/V0SPI_MISO: U2.39 (GPIO1/TOUCH1/ADC1_CH0); also elsewhere on the board
/ESP32-CM/V0SPI_MOSI: U2.15 (GPIO3/TOUCH3/ADC1_CH2); also elsewhere on the board
/ESP32-CM/V1SPI_CLK: U2.7 (GPIO7/TOUCH7/ADC1_CH6); also elsewhere on the board
/ESP32-CM/V1SPI_CS: U2.12 (GPIO8/TOUCH8/ADC1_CH7); also elsewhere on the board
/ESP32-CM/V1SPI_MISO: U2.5 (GPIO5/TOUCH5/ADC1_CH4); also elsewhere on the board
/ESP32-CM/V1SPI_MOSI: U2.6 (GPIO6/TOUCH6/ADC1_CH5); also elsewhere on the board
/SCL0: U2.18 (GPIO10/TOUCH10/ADC1_CH9/FSPICS0/FSPIIO4); also elsewhere on the board
/SCL1: U2.20 (GPIO12/TOUCH12/ADC2_CH1/FSPICLK/FSPIIO6); also elsewhere on the board
/SDA0: U2.17 (GPIO9/TOUCH9/ADC1_CH8/FSPIHD); also elsewhere on the board
/SDA1: U2.19 (GPIO11/TOUCH11/ADC2_CH0/FSPID/FSPIIO5); also elsewhere on the board
/~E1_INT: U2.22 (GPIO14/TOUCH14/ADC2_CH3/FSPIWP/FSPIDQS); also elsewhere on the board
/~E2_INT: U2.21 (GPIO13/TOUCH13/ADC2_CH2/FSPIQ/FSPIIO7); also elsewhere on the board
GND: C1.2, C4.2, C5.2, C6.2, S1.2 (COM), S1.4 (COM), U2.1 (GND), U2.40 (GND), U2.41 (GND); also elsewhere on the board

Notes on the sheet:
ESP32-S2-SOLO
Reset Button
Populate if previous implementation had no reset for the CM

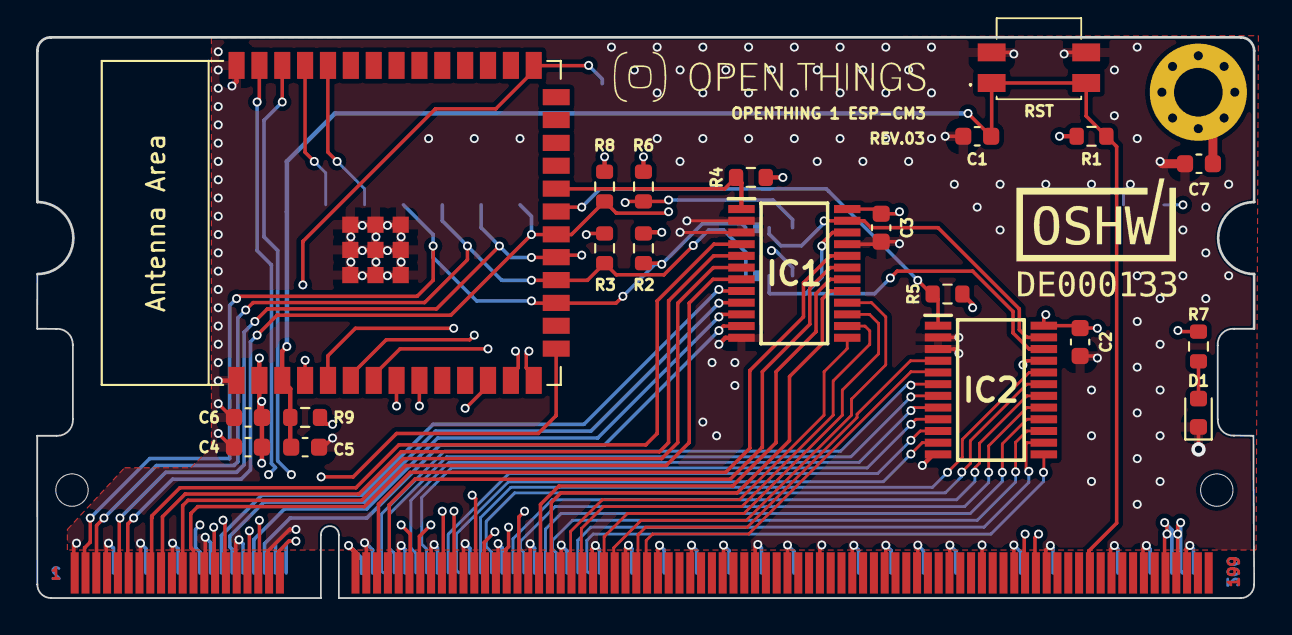
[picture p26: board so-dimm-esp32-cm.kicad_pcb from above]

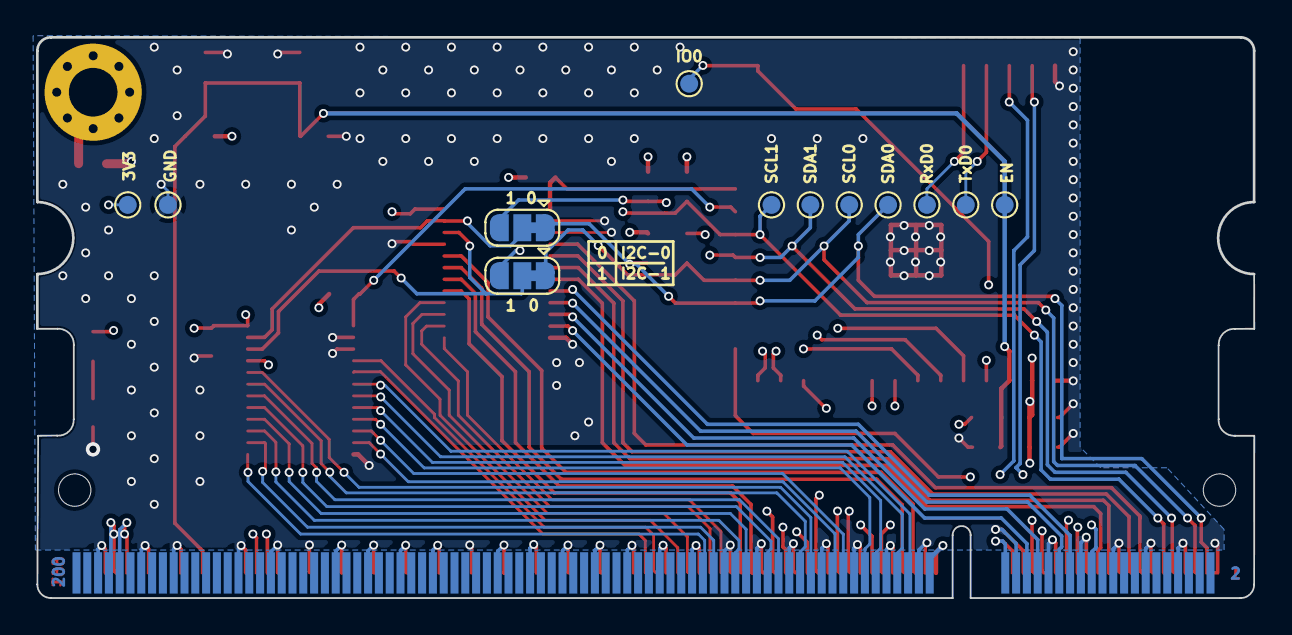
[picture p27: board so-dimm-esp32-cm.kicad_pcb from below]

Board: 4 copper layers, 67.6 x 31.1 mm, 37 parts (12 on the bottom side), 60 nets.

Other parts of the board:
G1, G2: LOGO

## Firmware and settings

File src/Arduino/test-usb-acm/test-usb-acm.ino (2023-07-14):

#include "usb/usb_host.h"

#include "usb_host.hpp"
#include "usb_acm.hpp"
#include "PI4IOE5V6416.h"

PI4IOE5V6416 ioex;

USBhost host;           // host is required to detect any device, before USB class is initialized
USBacmDevice *device;   // when USB class is detected from descriptor

void acm_events(int event, void *data, size_t len)
{
    switch (event)
    {
    case CDC_CTRL_SET_CONTROL_LINE_STATE:
        log_i("CDC_CTRL_SET_CONTROL_LINE_STATE");
        device->setLineCoding(115200, 0, 0, 8);
        break;

    case CDC_DATA_IN:
    {
        device->INDATA();
        char *buf = (char *)data;
        buf[len] = 0;
        printf("%s", (char *)data);
        break;
    }
    case CDC_DATA_OUT:

        break;

    case CDC_CTRL_SET_LINE_CODING:
        log_i("CDC_CTRL_SET_LINE_CODING");
        break;
    }
}

void client_event_callback(const usb_host_client_event_msg_t *event_msg, void *arg)
{
    if (event_msg->event == USB_HOST_CLIENT_EVENT_NEW_DEV)
    {
        host.open(event_msg);
        usb_device_info_t info = host.getDeviceInfo();
        log_i("device speed: %s, device address: %d, max ep_ctrl size: %d, config: %d", info.speed ? "USB_SPEED_FULL" : "USB_SPEED_LOW", info.dev_addr, info.bMaxPacketSize0, info.bConfigurationValue);
        const usb_device_desc_t *dev_desc = host.getDeviceDescriptor();
        int offset = 0;
        for (size_t i = 0; i < dev_desc->bNumConfigurations; i++)
        {
            const usb_config_desc_t *config_desc = host.getConfigurationDescriptor();
            for (size_t n = 0; n < config_desc->bNumInterfaces; n++)
            {
                const usb_intf_desc_t *intf = usb_parse_interface_descriptor(config_desc, n, 0, &offset);
                if (intf->bInterfaceClass == 0x0a) // CDC ACM
                {
                    device = new USBacmDevice(config_desc, &host);
                    n = config_desc->bNumInterfaces;
                    if (device)
                    {
                        device->init();
                        device->onEvent(acm_events);
                        device->setControlLine(1, 1);
                        device->INDATA();
                    }
                }

                printf("config: %d[%d], interface: %d[%d], intf class: %d\n", i, dev_desc->bNumConfigurations, n, config_desc->bNumInterfaces, intf->bInterfaceClass);
            }
        }
    }
    else
    {
        log_w("DEVICE gone event");
    }
}

void setup()
{
    Serial.begin(115200);

    Wire.begin();
    ioex.attach(Wire, 0x20);
    ioex.polarity(PI4IOE5V64XX::Polarity::ORIGINAL_ALL);
    ioex.direction(PI4IOE5V64XX::Direction::OUT_ALL);
    ioex.write(PI4IOE5V64XX::Level::L_ALL);
    ioex.write(PI4IOE5V64XX::Port::P02, PI4IOE5V64XX::Level::H);
    ioex.write(PI4IOE5V64XX::Port::P03, PI4IOE5V64XX::Level::L);

    host.registerClientCb(client_event_callback);
    host.init();
}

void loop()
{
    if (device && device->isConnected())
    {
        device->OUTDATA((uint8_t *)"test\n", 5);
    }
    delay(1000);
}

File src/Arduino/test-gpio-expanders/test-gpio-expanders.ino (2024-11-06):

#include <PI4IOE5V6416.h>
#include "I2CScanner.h"
#include <Wire.h>

PI4IOE5V6416 e1;
PI4IOE5V6416 e2;

I2CScanner scanner;
#define SDA_PIN 9	
#define SCL_PIN 10

void setup() {
    Serial.begin(115200);
    while (!Serial) {};

    scanner.Init();
    scanner.Scan();

    Wire.begin(9, 10);

    Serial.println("Set all pins to high");
    e1.attach(Wire, 0x20);
    e1.polarity(PI4IOE5V64XX::Polarity::ORIGINAL_ALL);
    e1.direction(PI4IOE5V64XX::Direction::OUT_ALL);
    e1.write(PI4IOE5V64XX::Level::H_ALL);

    Serial.println("Set all pins to high");
    e2.attach(Wire, 0x21);
    e2.polarity(PI4IOE5V64XX::Polarity::ORIGINAL_ALL);
    e2.direction(PI4IOE5V64XX::Direction::OUT_ALL);
    e2.write(PI4IOE5V64XX::Level::H_ALL);

    

    //e1.write(PI4IOE5V64XX::Port::P02, PI4IOE5V64XX::Level::H);
    //e1.write(PI4IOE5V64XX::Port::P03, PI4IOE5V64XX::Level::H);

    //e1.write(PI4IOE5V64XX::Port::P13, PI4IOE5V64XX::Level::H);  //opener/GPIO27rpi
    //Serial.println(e1.read(), BIN);

    //e2.write(PI4IOE5V64XX::Port::P07, PI4IOE5V64XX::Level::H);
    ///Serial.println(e2.read(), BIN);
}

void loop() {
      e1.write(PI4IOE5V64XX::Port::P02, PI4IOE5V64XX::Level::H);
      Serial.println("an");
      delay(1000);
      e1.write(PI4IOE5V64XX::Port::P02, PI4IOE5V64XX::Level::L);
      Serial.println("aus");
      delay(1000);
}

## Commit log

2022-10-22 initial commit REV0.1
    [EVQ-PUA02K.stl, EVQ-PUA02K.stp, IC57_RP2040.step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]
2022-10-22 removed unused files
    [esp32-cm.kicad_sch, esp32.kicad_sch]
2022-10-22 Switch version v2 to v2_k6
2022-10-22 reverse version switch
2022-10-22 fix ERC issues
    [cm-connector.kicad_sch, esp32-s2-solo.kicad_sch, so-dimm-esp32-cm.kicad_sch]
2022-10-22 remove components from the BOM which are DNP
    [cm-connector.kicad_sch, esp32-s2-solo.kicad_sch, so-dimm-esp32-cm.kicad_sch]
2022-10-22 remove components bom
    [so-dimm-esp32-cm.kicad_pcb]
2023-01-04 Added jumper to swap I2C-0 with I2C-1 for the GPIO-Expanders
    The GPIO expanders are using 0x20 and 0x21 as addresses and to avoid clashes with existing carrierboards I made the I2Cchannel switchable. Default is I2C-0 now
    [cm-connector.kicad_sch, so-dimm-esp32-cm.kicad_pcb, so-dimm-esp32-cm.kicad_sch]
2023-01-04 Fix ERC warnings
    [esp32-s2-solo.kicad_sch, so-dimm-esp32-cm.kicad_pcb, so-dimm-esp32-cm.kicad_sch]
2023-03-24 Refactored PCB Layer to have one dedicated GND Layer + rerouted traces + removed debug connector and added IO0 to the SO-DIMM connector + added decoupling caps and delay circuit for ESP32 module
    [ESP32-S2-SOLO-N4R2.stp, cm-connector.kicad_sch, esp32-s2-solo.kicad_sch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]
2023-04-03 Convert to KiCad 7
    [cm-connector.kicad_sch, so-dimm-esp32-cm.kicad_pcb]
2023-07-14 Add arduino test code
2023-07-14 Generated BOM and schematics
2023-07-14 Add IMG of the board
2023-08-11 Fix missing ESP-SOLO footprint and Symbol
    [EVQPU-JA-02K.STEP, cm-connector.kicad_sch, esp32-s2-solo.kicad_sch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]
2023-08-11 Moved ESP SOLO 3D File into project
    [ESP32-S2-SOLO-N4R2.stp, so-dimm-esp32-cm.kicad_pcb]
2023-09-01 Added Via stitching and ground plane to top and bottom layers
    [AW9523BTQR.stp, so-dimm-esp32-cm.kicad_pcb]
2023-09-01 Changed camera angle for the 3D rendering
2023-09-02 Update esp-cm3.kibot.yaml to print PNG of the PCB
2023-09-03 Changed from pcb_print to pcb draw
2023-09-08 Added inner layers to Gerber files for KiBot
2023-09-11 Added CE Sign + Moved footprint a tiny bit + added so-dimm numbering silk + increased revision number
    [so-dimm-esp32-cm.kicad_pcb]
2023-09-11 Added Datasheet config
    [so-dimm-esp32-cm.kicad_sch]
2023-09-18 Fix SO-DIMM Pinout differences to DDR2 CM3 + Added ground drill
    [so-dimm-esp32-cm.kicad_pcb, so-dimm-esp32-cm.kicad_sch]
2023-09-21 Add panelisation edges
    [so-dimm-esp32-cm.kicad_pcb]
2023-09-25 Added KiBot configs for PCBWay and JLCPCB
2023-09-27 Finally fix SODIMM Pin layout based on datasheet of the 1612618 connector
    [so-dimm-esp32-cm.kicad_pcb]
2023-09-29 Set reset button to be DNP
    [esp32-s2-solo.kicad_sch, so-dimm-esp32-cm.kicad_pcb]
2023-09-29 Removed mounting hole from BOM
    [so-dimm-esp32-cm.kicad_pcb]
2023-10-09 Change copper to edge clearance from 0.025 to 0.15
    [so-dimm-esp32-cm.kicad_pcb]
2024-03-20 Removed parts from BOM and applied clearence changes
    [esp32-s2-solo.kicad_sch, so-dimm-esp32-cm.kicad_pcb, so-dimm-esp32-cm.kicad_sch]
2024-03-21 Ignored thermal-relief + changed ESP32-S2 to be ESP32-S3-N8
    [esp32-s2-solo.kicad_sch, so-dimm-esp32-cm.kicad_pcb]
2024-03-21 Added assembly file + bom XLSX File (K&G)
    [ESP-CM3-BOM.xlsx, so-dimm-esp32-cm.kicad_pcb]
2024-03-21 Added Generated production data
    [ESP-CM3-BOM-K&G.xlsx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]
2024-11-06 Add some test classes for arduino code and toit
2024-11-06 Moved some silkscreen to user drawings
    [so-dimm-esp32-cm.kicad_pcb]
2024-11-06 add production data board dimensions and specification
